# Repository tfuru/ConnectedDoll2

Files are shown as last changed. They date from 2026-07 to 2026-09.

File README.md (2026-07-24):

# オーディオストリーミングスタンド開発ボード ver.2
XIAO ESP32C3 に TFカード, RTC, オーディオアンプ  などを追加したオーディオストリーミングボード

## 参考ボード
[オーディオストリーミングスタンド開発ボード](https://github.com/bit-trade-one/ADE32CD-Connected-Doll) 

## 基板,外装
[board README.md](./board/circuit)

## ファームウェア
[firmware README.md](./board/firmware)

## サンプルアプリ
[app README.md](./app/)

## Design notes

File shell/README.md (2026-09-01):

# オーディオストリーミングスタンド開発ボード ver.2 ケース（外装）データ
XIAO ESP32C3 に TFカード, RTC, オーディオアンプなどを追加したオーディオストリーミングボード ケースのデータ

本ケースの3Dモデルデータは **OpenSCAD**（`.scad`）を用いてパラメータ設計・作成します。

## ケース イメージ図
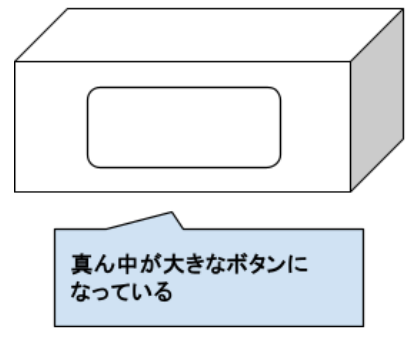
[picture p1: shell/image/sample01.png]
sample01
  
- 上下2分割（トップカバー / ボトムケース）構造の正方形ケース
- トップカバーの手前側面（フロント）に大型プッシュボタンを配置
- ボトムケース内部底面にスピーカー固定用ネジ穴を配置

## 主な部品

### 1. オーディオストリーミングスタンド開発ボード ver.2 基板
- **基板寸法**: 60mm × 60mm
- **角丸**: R = 2.0mm
- **取付穴**: 四隅 52mm × 52mm 位置に M2 ネジ穴
- **基板搭載部品**: XIAO ESP32C3, 横向きタクトスイッチ(EVQPUC02K), オンボードLED(WS2812B), 音量調整用アナログ可変抵抗, 各種コネクタ

### 2. スイッチ付き 単4電池×3本 電池ボックス
- **外形寸法**: 長さ 63.0mm × 幅 37.0mm × 高さ 17.0mm
- 電源スイッチ付き（スライドスイッチ）
- 配線取り出し口あり

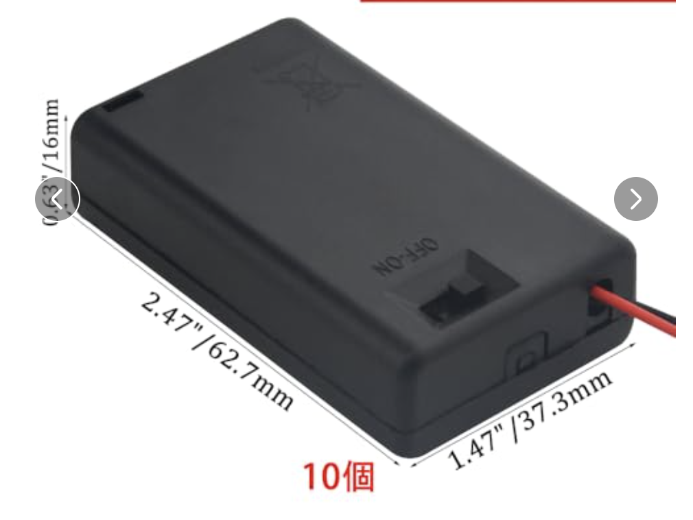
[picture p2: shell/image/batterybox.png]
batterybox


### 3. スピーカー TR-WS-2014B
- **本体外形寸法**: 20.0mm × 13.9mm × 厚み 4.5mm (取付フランジ含め 全幅 28.5mm)
- **取付穴ピッチ**: 24.7mm (M1.8ネジ対応)
- **出音口**: 取付耳側の長手側面スロットおよび前面開口（ケース前方 -Y 方向に向けて配置）
- **固定**: ボトムケース底面の M1.8 固定ボス（Y = -31.0mm / 前面方向へ2.5mm移動し電池ボックスとの間に1.75mmクリアランスを確保）にネジ止め

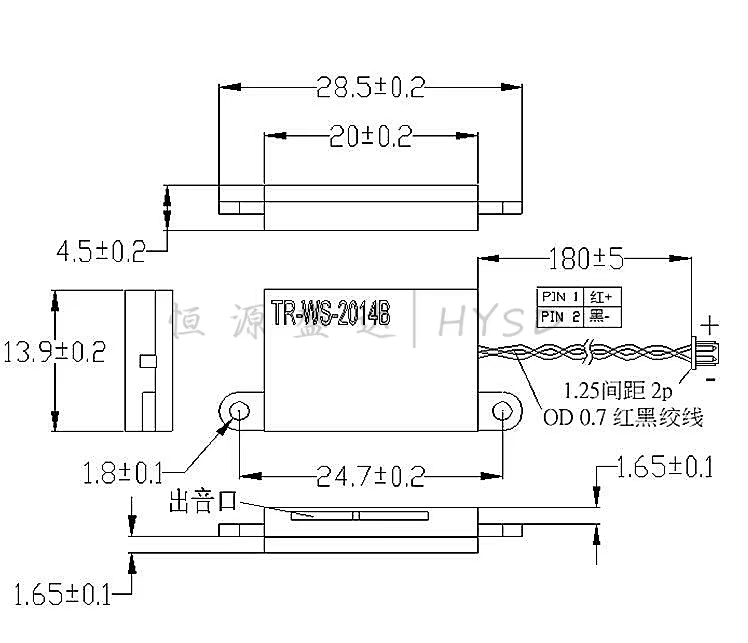
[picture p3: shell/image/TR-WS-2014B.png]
TR-WS-2014B


## ケース設計仕様

### 1. 構造 & レイアウト仕様
- **ケース形状**: 上下2分割ケース（外寸 約 68.8mm × 71.8mm、手前側壁を前方に +3.0mm 拡張して基板との間に 4.2mm の広大なクリアランスを確保）
- **トップカバー**:
  - 薄型リッド（天板カバー、高さ 8.0mm）
  - 上下締結ボス（M2 おねじ受けタッピングボス）
  - **右側面**: 音量調整用 スリット上部切り欠き＆指掛かりスカラップ＋**内側補強土手**（高さ3.0mm切り欠き、幅24.0mm×深さ1.4mmの45度テーパーすり鉢面取り。内壁側に厚み1.3mmの補強土手を盛り上げ、スカラップ切削後も純残存肉厚1.9mm〜2.0mmを完全担保）
- **ボトムケース**:
  - **フロント側面**: 大型プッシュボタン用 開口部（約 44mm × 18mm, R=3mm）
  - **右側面**: 音量調整用 スリット開口部＆指掛かりスカラップ＋**内側補強土手**（**20mmスペーサー対応 天端開放Uノッチ構造 & 45度すり鉢状スカラップ & 内側裏打ちフレーム**: 開口幅18.0mm × 高さ3.3mm, 開口範囲 Z = 24.7mm〜28.0mm, 外壁に幅24.0mm×深さ1.4mmのすり鉢状指逃げ凹みを形成。ケース内側に厚み1.3mmの補強土手を一体化して総肉厚3.3mmとすることで、スカラップ加工後の最薄部でも**純残存肉厚1.9mm〜2.0mm（基準1.5mm以上）**を確実に確保。合わせ面リム幅も2.0mm以上を維持し、基板端面（X=64.4mm）との間にも1.1mmの安全クリアランスを保持）
  - **内部底面**:
    - スピーカー（TR-WS-2014B）固定用ボス（M1.8, ピッチ24.7mm / 手前前面側）
    - **電池ボックス底面取り出し開口ベイ (64.0mm × 38.0mm)**: ケース分解不要で底面から電池ボックスを抜き差し可能
    - **高剛性 電池フタ受け座補強フレーム (上面 Z = 3.6mm, 実肉厚 2.0mm)**: リセス座面（幅1.5mm）をケース内側へ+1.6mm盛り上げ、従来の極薄0.4mmから2.0mm（5倍）へ大幅増強。手前ツメ受けスリット天井も含めて一体強化し、薄肉折損を完全根絶
    - **基板保護天井ストッパーリブ (Z = 19.2mm, 厚み2.2mm, 下面45度ブレース付き)**: 電池ボックスを底面から挿入した際に基板裏面（Z = 23.4mm）との間に安全空間（4.2mm）を保持。右側面ボリュームスリット開口部（Z=24.7mm〜28.0mm）より遥か下（Z≤21.4mm）に完全収容し、スリット開口・ダイヤル操作に一切干渉せず、下面45度テーパーブレースと垂直ガイド壁（幅20mm）の全面一体支持により折損を完全防止
    - **背面壁・底面一体型 垂直ガイドリブ (下面三角ブレース付き)**: 浮遊構造を完全排除し、背面内壁（Y=69.8mm）および健全な底面から前方開口端（Y=57.9mm）へ伸びる左右対称の垂直リブにより、電池ボックスの奥側ズレを適正クリアランス（0.5mm）で確実に拘束
    - **側壁垂直ガイドレール**: 電池ボックスの横揺れを抑え、スムーズな抜き差しを実現
    - **高剛性 M2六角スペーサー受け座パッド (52×52mmピッチ, パッド高2.4mm, 回り止め六角ポケット付, 締結座面肉厚 2.0mm)**: 底面ザグリ穴（深さ1.4mm）との間で実効肉厚 2.0mm（旧0.4mmの5倍）を確保し、ネジ締め付け時の割れ・突き抜けを完全防止
    - **回転ロックダイヤル受け座 & 補強台座ブロック**: 底面沈め込みポケット（深さ2.4mm）の真上を背面壁直結の頑丈な台座ブロック（厚み4.0mm）で完全被覆。内側からM2ネジ1本で保持され脱落しない高剛性キャプティブ構造
  - **底面外装 & 電池フタ**:
    - **高剛性アンダーカット潜り込み引っ掛け式 電池フタ (`battery_lid.scad`)**: 底面段差リセス（67.0×41.0mm）に対して全周 0.55mm の隙間（フタ外寸 65.9×39.9mm）を確保。フタ手前側のツメは底面外側表面に露出させず、裏面ステップ（Z=1.6mm〜2.7mm）から手前へ突出させてボトムケースのリセス座面裏側（厚み1.6mmの強固なフランジ）へ潜り込ませて係止。ボトム側スリット天井には高さ Z=4.8mm まで盛り上げた補強土手（純残存肉厚1.6mm確保）を設け、内部に電池ボックスを収容しても自重やスプリングの反力によるフタの浮き上がりを物理的に完全防止。外観は底面表面にツメ切り欠きのない美しいフラットデザイン
    - **スイッチアクセス開口窓 (幅23.0mm × 奥行き14.0mm, 角丸R2.5mm, 広大すり鉢状面取り1.8mm付き, 後方+5.0mmオフセット)**: 実機電池ボックスのスイッチ位置に合わせて後方へ+5.0mmシフト配置。スイッチの全可動範囲（ノブ右端・左端）を開口中央で完全にカバーし、成人の指の腹や爪先でフタを開けることなく軽快にON/OFF直接操作可能
    - **キャプティブ回転ロックダイヤル (`rotary_lock.scad`)**: 指先つまみリブ（コイン溝兼用）、Dカット施錠カム、90度回転リミッター内蔵
- **ポート・開口部の扱い**:
  - **Type-C ポート**: ケース開口なし（内部密閉）
  - **MicroSD スロット**: ケース開口なし（内部密閉）
  - **ボリューム**: 右側面スリットからダイヤル操作
  - **電源スイッチ**: ケース底面のスイッチアクセス開口窓から直接操作

### 2. 前面大型ボタン機構（側面配置・コイルスプリング＆インセット式M2アジャスタブル・プランジャー）
- ボトムケースの正面側壁に大型ボタンパーツを配置。
  - **基板接触回避・上方向+2.0mmシフト**: 20mm支柱スペーサー上の基板表面（Z=25.0mm）に対してネジ頭（φ3.5mm）が接触・干渉するのを完全に回避するため、プランジャーネジ位置を上方向へ +2.0mm オフセット（ボタン中心からのオフセット Y = +3.625mm, ネジ中心高さ Z=27.825mm）。ネジ頭下端（Z=26.075mm）と基板表面の間に 1.075mm の安全空間を確保しつつ、タクトスイッチ（EVQPUC02K）のアクチュエータを確実に押下。
  - **高肉厚・M2ネジ貫通防止構造**: ボタン全厚を **6.0mm**（ボタンキャップ厚み 4.2mm ＋ フランジ厚み 1.8mm）へ増厚。ケース外壁から 2.2mm 突出し、ストローク時も埋没せず快適な押し心地と高いガイド剛性を実現。
  - **インセット（埋め込み）ポケット ＆ 安全肉厚2.0mm確保**: ボタン裏面に深さ 1.5mm（φ5.0mm）のネジ頭収容ポケットおよび深さ 2.5mm のタッピング下穴を配置。全厚 6.0mm に対し穴底から表面まで **2.0mm** の安全肉厚を確保し、推奨 M2 なべ小ねじ（L=4mm）を奥まで締め切っても表面を一切貫通しない設計。
  - **基板との適正クリアランス（3.6mm）**: ボタンフランジ裏面から基板前端面まで **3.60mm**、タクトスイッチ接触面まで **3.80mm** の十分な可動・調整空間を確保。
  - **M2ネジによる無段階クリアランス調整**: M2 なべ小ねじ（L=4mm 推奨）をねじ込み、ドライバーでねじ込み深さを回すだけでスイッチ先端とのクリアランス（0.2mm〜0.5mm）および押し込み深さを自由に微調整可能。
- **市販マイクロコイルスプリング（押しバネ）復帰機構 & 高剛性・耐折損受け座ボス構造**:
  - ボタン裏面左右2箇所に φ3.4mm ポケットを設け、外径 φ3.0mm × 自由長 6〜8mm のマイクロコイルスプリングをボトムケース受け座ボスとの間に挟み込み、スムーズでガタつきのない極上の復帰フィーリングを実現。
  - **D型長円スパイン構造（曲げ剛性・断面係数3倍増）**: 直径 φ5.4mm の前方円筒の背後に φ6.2mm の後方スパイン円柱を一体化し、奥行きを 8.2mm に拡張。バネ穴裏面の肉厚を 2.9mm → 5.8mm（2倍）に倍増してノッチ破断を完全防止。
  - **前面壁直結サポートブロック（片持ち梁長さを半減）**: ボタンフランジ下端（Z=14.6mm）より下のデッドスペース（Z=0〜10.5mm）を全面活用し、ボス前面からケース前面内壁までを中実ブロックで直結一体化。実効的な片持ち長を 19.4mm → 9.5mm に半減し、曲げ応力を約 1/8 に低減。
  - **3方向三角ブレース ＆ 根元裾野テーパー**: ボタン押下・バネ圧縮荷重を受け止める後方 45° 三角ブレース（t=2.0mm）、横揺れや印刷時振動を抑える外側横ブレース（t=2.0mm）、底面裾野テーパーを配備。
  - **頂部肉厚の最適化**: ボス高さを Z=20.0mm に設定し、基板下面（Z=23.4mm）との 1.4mm クリアランスを保ちつつ、バネ穴上部の肉厚を 1.0mm → 1.6mm（+60%）に増厚。
- がたつき防止ガイドおよび適度な押下ストローク（約0.4〜1.0mm）を確保。

### 3. 締結・固定仕様 & 使用ネジ一覧
- **六角スペーサーによる基板独立固定 ＆ トップカバー直接締結構造**:
  - **下部 20mm スペーサー**: ボトム底面四隅（52mm × 52mm ピッチ）に **M2 六角両メススペーサー（20mm）** を配置し、底面ザグリ穴から **M2 × 5mm なべ小ねじ** で強固に締結。
  - **基板上 5mm スペーサー（基板独立固定）**: 基板表面の四隅に **M2 六角スペーサー（5mm: オスメスまたは両メス＋スタッド）** をねじ込み、基板を 20mm スペーサーとの間に単独で強固にクランプ固定。トップカバーを開閉しても基板が一切外れない抜群のメンテナンス性を実現。
  - **トップカバーからのダイレクト締結（ボス高 4.0mm ＆ M2 × 8mm ネジ）**:
    - 5mm スペーサー天面（Z = 30.0mm: ボトム天端 Z=28.0mm から 2.0mm 突出）を受け止めるため、トップカバー内側ボスの高さを **4.0mm** に設定。
    - トップカバー天面ザグリ穴（深さ1.4mm）から **M2 × 8mm なべ小ねじ** を挿入し、ボスを介して 5mm スペーサー上部めねじへ直接締結（樹脂肉厚 4.6mm ＋ スペーサーねじ込み深さ 3.4mm で強固に締結）。
- **回転ロックダイヤル固定**: 底面外側から **M2 × 5mm なべ小ねじ** をダイヤル中心穴へ貫通させ、ボトムケース側ソリッドボスのタッピング穴へ締結。ネジ頭はダイヤル表面ザグリ穴（深さ1.3mm）に完全沈み込み、外側からドライバー1本で着脱・回転トルク調整が容易なキャプティブ構造。
- **スピーカー**: ボトムケース底面の固定ボス（M1.8, 24.7mmピッチ）へネジ止め固定

#### 必要ネジ・金具規格および推奨長さ一覧

| 用途 / 締結箇所 | 規格 | 数量 | 推奨ネジ長さ (首下長) | 備考・締結内訳 |
| :--- | :--- | :---: | :--- | :--- |
| **メイン基板下部支柱** | **M2 六角両メススペーサー** | **4本** | **スペーサー長 20mm (二面幅4.0mm)** | ボトム底面と基板下面の間を支柱固定（下部めねじ締結） |
| **メイン基板固定スペーサー** | **M2 六角スペーサー** | **4本** | **スペーサー長 5mm (二面幅4.0mm)** | 基板表面四隅にねじ込み基板を独立固定、上端天面でトップカバーを着座受座 |
| **トップカバー締結** | **M2 なべ小ねじ** | **4本** | **L = 8 mm (6mm〜8mm)** | 天面ザグリから挿入しボス(4.0mm)を介して5mmスペーサー上部へ直接締結 |
| **ボトムケース・スペーサー締結** | **M2 なべ小ねじ** | **4本** | **L = 4 mm 〜 6 mm (推奨 5mm)** | ボトム底面ザグリ穴から挿入し20mmスペーサー下部めねじへ締結 |
| **回転ロックダイヤル支柱ピン** | **M2 なべ小ねじ** | **1本** | **L = 4 mm 〜 6 mm (推奨 5mm)** | 底面外側からダイヤル中央を貫通させボトム側ボスへ締結（外側から調整容易） |
| **前面ボタン調整プランジャー** | **M2 なべ小ねじ** | **1本** | **L = 4 mm 〜 6 mm (推奨 4mm)** | ボタン裏面ボスへねじ込み、タクトスイッチ押下量を無段階微調整 |
| **前面ボタン復帰押しバネ** | **マイクロコイルスプリング** | **2本** | **外径 φ3.0mm × 自由長 6〜8mm (線径0.3mm)** | ボタン裏面とボトムケース受け座の間に挟み込み、滑らかな復帰動作を実現 |
| **スピーカー固定** | **M1.8 タッピングねじ (または M1.7〜M2)** | **2本** | **L = 4 mm 〜 5 mm** | スピーカー耳フランジ(1.0mm) ＋ ボス有効深さ(3.5〜4.0mm) |
| **前面ボタン用吸着磁石** | **ネオジム磁石** | **2個** | **φ6.0mm × 厚み 3.0mm (または2.0〜3.0mm)** | ボタン表面左右の円筒ポケット（深さ3.0mm/径6.4mm, 導入テーパー付）に圧入・接着し、化粧パネル側M2ナットを吸着 |
| **化粧パネル用吸着ナット** | **M2 六角ナット (JIS規格/スチール製)** | **2個** | **厚み 1.6mm (二面幅 4.0mm)** | 化粧パネル左右の六角穴（二面幅4.4mm）に圧入・接着 |

### 4. 完全工具レス 電池交換手順
1. ケース底面の回転ロックダイヤルをつまみ、指先で90度回して「OPEN」位置（刻印マーク合わせ）にします。
2. 電池フタ奥側の指掛けネイルノッチに爪を掛け、フタを持ち上げて手前に引き抜きます。
3. 電池ボックスを底面開口から引き出し（リード線余裕長 50mm）、電池ボックスのフタをスライドさせて単4電池×3本を交換します。
4. 電池ボックスを内部へ戻し、電池フタを手前斜め約15°に傾けて手前の2箇所のツメをボトム内側のスリットへ潜り込ませ、パタンと倒してリセス座面へ収めます。
5. 回転ロックダイヤルを「LOCK」位置へ90度回して確実に施錠します。

## 構成パーツ一覧（OpenSCAD ファイル構成）
- **共通パラメータ**: `scad/params.scad`
1. **トップカバー**: `scad/top_cover.scad`
   - 手前側面エプロン壁、天面M2ネジ頭ザグリ穴（φ4.4mm × 1.8mm）、全通貫通穴（φ2.2mm）、基板押さえボス（高さ10.2mm）
2. **ボトムケース**: `scad/bottom_case.scad`
   - 前面大型ボタン開口部、右側面ボリュームスリット、スピーカー固定ボス（M1.8）、**底面電池取り出し開口ベイ（64×38mm）**、**回転ロック受け座ポケット＆90度リミッター溝**、**電池フタ受け座段差リセス**、**内側アンダーカットツメ受けスリット（Z=1.6〜3.2mm）＆スリット天井補強梁（Z=4.8mm）**、**内部基板保護天井ストッパー（Z=19.2mm）＆垂直ガイドレール**、前面スピーカー出音用スリット（7連バーチカルスリット）
3. **電池フタ（バッテリーリッド）**: `scad/battery_lid.scad`
   - 裏面手前側アンダーカット差し込み係止ツメ（左右2箇所, Z=1.6〜2.7mm）、**スイッチアクセス開口窓（23×14mm, テーパー面取り付き, 後方+5.0mmオフセット）**、奥側回転ロック受座円弧シェルフ（Dカット逃げ付き）、指掛けネイルノッチ
4. **回転ロックダイヤル**: `scad/rotary_lock.scad`
   - 指先つまみリブ（コイン溝兼用）、外周滑り止めセレーション、90度回転制動リミッターピン、Dカット施錠カム、**中心M2ネジ頭沈めザグリ穴＆貫通ピボット穴**
5. **前面ボタン（ボタンキャップ）**: `scad/front_button.scad`
   - 側面操作用大型ボタン、M2ネジ式アジャスタブル・プランジャーボス、裏面 左右2箇所 φ3.4mm コイルスプリングポケット、表面左右2箇所 φ6.4mm ネオジム磁石接着ポケット（導入テーパー付）
6. **3Dプリント一括出力用プレート**: `scad/print_plate.scad`
   - **超コンパクト垂直スタック一体型モデル**: ボトムケースの外寸（約 $69\text{mm} \times 72\text{mm}$）内に、電池フタおよび回転ロックダイヤルを中間層として完全内包スタック。部品間を離さずにベッド専有面積を最小化（約55%削減）し、全パーツ間に薄首サポートピラー（くびれ径 $\phi 1.3\text{mm}$）を配置。印刷後にニッパーでパチンと簡単に切り離せるランナーキット構造。（※前面ボタンは別色印刷対応のため単体 `front_button.stl` を推奨、`include_button=true` で追加可能）
7. **全体アセンブリ確認用**: `scad/main_assembly.scad`
   - 各パーツおよび基板・電池ボックス・スピーカー・締結ネジ・電池フタ・回転ロックの配置・干渉確認用（施錠/解錠および下方向分解シーケンス対応）

## STL 出力スクリプト
OpenSCAD CLI（コマンドライン）を利用して各 `.scad` ファイルから 3D プリント用 STL ファイルを一括・自動生成するビルドスクリプト（`export_stl.sh`）を作成・提供します。

- **出力予定 STL ファイル**:
  - `stl/print_plate_all.stl`（**★超コンパクト一括スタック印刷用**: ボトム＋フタ＋ロック＋トップを垂直スタック＆ニッパー切り離しサポート付きで 1 回でまとめてコンパクト印刷）
  - `stl/top_cover.stl`（トップカバー単体）
  - `stl/bottom_case.stl`（ボトムケース単体）
  - `stl/front_button.stl`（前面大型ボタン単体）
  - `stl/acrylic_panel.stl`（アクリル化粧パネル 3Dモデル）
- **アクリル加工用 2D ベクターファイル**:
  - `acrylic/acrylic_panel.dxf`（レーザーカット用 DXF）
  - `acrylic/acrylic_panel.svg`（レーザーカット / イラスト用 SVG）
- **プレビュー画像出力先**:
  - `image/dist/` 配下にレンダリングプレビュー画像（`print_plate_preview.png`, `top_cover_preview.png`, `bottom_case_preview.png`, `front_button_preview.png`, `acrylic_panel_preview.png`, `assembly_exploded.png`, `assembly_closed.png`）を自動生成

### コマンド例

#### スクリプトによる一括出力
```bash
# スクリプトに実行権限を付与して実行
chmod +x export_stl.sh
./export_stl.sh
```

#### 個別パーツのコマンドライン出力 (OpenSCAD CLI)
```bash
# 出力先ディレクトリの作成
mkdir -p stl image/dist

# 各パーツを STL としてレンダリング・出力
openscad -o stl/top_cover.stl scad/top_cover.scad
openscad -o stl/bottom_case.stl scad/bottom_case.scad
openscad -o stl/front_button.stl scad/front_button.scad
```

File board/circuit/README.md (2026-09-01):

# オーディオストリーミングスタンド開発ボード ver.2
XIAO ESP32C3 に TFカード, RTC, オーディオアンプ などを追加したボード

## 部品
JLCPCB にある部品を選定する 事とする   
https://jlcpcb.com/parts

| 回路種類 | 部品名 | 型番 | パッケージ |  JLCPCB Part | 備考 |
| ---- | --- | --- | ---- | ---- | --- |
| メインマイコン | マイコンボード | XIAO ESP32C3 | MODULE (17.8x21mm) | C19189385 | |
| オンボードLED | フルカラーLED  | WS2812B | SMD-5050 (5.0x5.0mm) | C4154882 | |
| 電源接続 | DCプラグコネクタ (外径5.5 mm、内径2.1 mm) | DC-005 2.0 | DIP | C16214 | Pin4: +5V, Pin2,3: GND |
| | 電源入力用コネクタ (PH) | B2B-PH-K-S(LF)(SN) | DIP | C131337 | 2pin PHコネクタ (オス, Pin1: +5V, Pin2: GND) |
| DCDC電源 | スイッチング電圧レギュレータ 3.3v | SY8089AAAC | SOT-23-5 | C78988 | |
||インダクタ 1.5μH / 6.3A | SMNR5040-1R5MT | SMD (5.0x5.0mm) | C467130 | 在庫あり代替品（シールド付） |
|| 積層セラミックコンデンサ 22μF / 16V | CL31A226KOCLNNC | SMD-1206 (3216) | C45783 | |
|| 精密チップ抵抗 45.3kΩ (±1%)| 0603WAF4532T5E | SMD-0603 (1608) | C23058 | |
|| 精密チップ抵抗 10kΩ (±1%) | RC0603FR-0710KL | SMD-0603 (1608) | C98220 | 在庫あり代替品 |
| 保護回路 | リセッタブルヒューズ | BSMD1206-110-16V | SMD-1206 (3216) | C2803346 | |
| 信号変換 | レベルシフタ | 74AHCT1G125GW | SOT-353 | C12495 | |
|| チップ抵抗 330Ω (±1%) | 0603WAF3300T5E | SMD-0603 (1608) | C23138 | |
| 逆流防止 | Pch MOSFET | AO3401A | SOT-23 | C15127 | |
|| ツェナーダイオード 5.1V | BZT52C5V1S | SOD-323 | C2118 | 在庫あり代替品 |
|| チップ抵抗 (±1%) 100kΩ | 0603WAF1003T5E | SMD-0603 (1608) | C25803 | |
| LED自動電源 | Pch MOSFET (ロードスイッチ) | AO3401A | SOT-23 | C15127 | 逆流防止用と共通 |
|| Nch MOSFET (ゲート駆動) | AO3400A | SOT-23 | C20917 | JLCPCB Basic Part |
|| 高速スイッチングダイオード | 1N4148WS | SOD-323 | C2128 | JLCPCB Basic Part (ピーク検波用) |
|| チップ抵抗 (±1%) 100kΩ | 0603WAF1003T5E | SMD-0603 (1608) | C25803 | プルアップ / プルダウン用 |
|| 積層セラミックコンデンサ 0.1μF | CL10B104KO8NNNC | SMD-0603 | C14663 | ピーク検波平滑用 |
| TFカード |  | DM3D-SF | SMD | C719027 | |
| RTC |  | DS3231MZ+TRL | SOIC-8 | C107410 | |
| オーディオ | オーディオアンプ | MAX98357AETE+T | TQFN-16-EP(3x3) | C910544 | |
| 操作UI | アナログ可変抵抗 10kΩ | RK10J11R0A0H | SMD | C470766 | 音量調整用 |
| | タクトスイッチ | EVQPUC02K | SMD (4.7x4.5mm) | C79174 | D0ピン(IO2)接続用 (横向きSMD) |
| 外部接続 | スピーカー接続用コネクタ (PH) | B2B-PH-K-S(LF)(SN) | DIP | C131337 | 2pin PHコネクタ (オス, 2.0mmピッチ) |
| | スピーカー接続用コネクタ (SH) | BM02B-SRSS-TB(LF)(SN) | SMD | C160388 | 2pin SHコネクタ (オス, 1.0mmピッチ, トップエントリー) |
| RTC電源 | CR1220用電池ホルダー | CR1220-2 | SMD | C70381 | 時刻バックアップ用保持器 |
| 電源/各IC | パスコン (積層セラ) 0.1μF | CL10B104KO8NNNC | SMD-0603 | C14663 | 各ICの電源用 (デカップリング) |
| | パスコン (積層セラ) 10μF | CL21A106KOFNNNE | SMD-0805 | C19702 | 電源平滑, アンプ電源補強, WS2812Bノイズ対策用 |
| | バルクコンデンサ (積層セラ) 47μF / 10V | CL31A476MPHNNNE | SMD-1206 (3216) | C96123 | 5V (V_BATT) 電源平滑・ESP32C3ノイズ対策用 |
| 通信ライン | プルアップ抵抗 1.5kΩ | 0603WAF1501T5E | SMD-0603 | C22843 | I2C(SDA/SCL)プルアップ用 |

## 回路参考

### 電源・保護回路 ブロック

Pch MOSFET (AO3401A) を用いた標準的な逆接続保護（ハイサイド）回路とする。

```
[DCジャック (DC1) Pin4 / PH端子 (CN3) Pin1 (+5V入力)] ──┬──> [AO3401A (C15127) の S(ソース)ピン]
                                                        │
                                                        └──> [ツェナーダイオード (C2118) の カソード(陰極)]

[AO3401A の G(ゲート)ピン] ──┬──> [ツェナーダイオード (C2118) の アノード(陽極)]
                             │
                             └──> [プルダウン抵抗 100kΩ (C25803)] ──> [GND]

[AO3401A の D(ドレイン)ピン] (正しく電源が入るとここから保護された電源が出力される)
    │
    └──> 🌟 ここが【リセッタブルヒューズ (C2803346)】の入力へ繋がります

※ 動作原理:
  - S(ソース) = +5V入力、D(ドレイン) = 保護後出力。
  - G(ゲート)は 100kΩ で GND へプルダウンされ、正常時 Vgs が負電圧となり MOSFET がON。
  - ツェナーダイオードは カソード=S(+5V側) / アノード=G(ゲート側) に接続し、
    Vgs を約5.1Vにクランプして MOSFET のゲート・ソース間を過電圧から保護する。
  - 逆接続時は Vgs が正となり MOSFET がOFFのまま導通しないため、後段を保護する。
```

```
[AO3401A の D(ドレイン)ピン] ──> [リセッタブルヒューズ (C2803346)] ──┬──> 🌟 各回路の【V_BATT】へ分配
                                                                      │
                                                                      └──> [バルクコンデンサ 47μF (C96123)] ──> [GND]

[電池のマイナス(−)] ───────────────────────────────> 🌍 すべての部品の【GND】へ接続
```

### 3.3V DCDCコンバータ回路 ブロック

```
                                 [インダクタ 1.5μH (C467130)]
                                     ┌─── LL ───┐
                                     │          │
[V_BATT] ──┬──> [IN (Pin4)] ─────── LX (Pin3)   ├──┬──> 🌟 各部品の【3.3V】電源へ
           │       │                            │  │
           │    [EN (Pin1)]                     │  └──> [コンデンサ 22μF (C45783)] ──> [GND]
           │                                    │
    [コンデンサ 10μF (C19702)]                  ├──> [分圧抵抗 45.3kΩ (C23058)]
           │                                    │         │
          [GND]                                 │      FB (Pin5)
                                                │         │
                                                │      [分圧抵抗 10kΩ (C25804)]
                                                │         │
                                                │        [GND]
                                                │
                                                └─────── [GND (Pin2)]

※ SY8089AAAC (C78988) は SOT-23-5 パッケージです。
```

### レベルシフタ ＆ LED回路 (自動電源遮断機能付き) ブロック

```
[XIAO D3 (GPIO5)] ──┬──> [74AHCT1G125GW (C12495) の A (Pin2)]
                    │
                    └──> [ダイオード 1N4148WS (C2128) の アノード]
                                │ (カソード)
                                ├──┬──> [Nch MOSFET AO3400A (C20917) の G(ゲート)]
                                │  │
                       [コンデンサ 0.1μF]  [プルダウン抵抗 100kΩ]
                                │  │
                               [GND]

[V_BATT] ──┬──> [Pch MOSFET AO3401A (C15127) の S(ソース)]
           │           │
     [プルアップ 100kΩ]  └── [D(ドレイン)] ──┬──> 🌟 各LED関連回路の【V_LED】電源へ
           │                               │
           ├───────────────────────────────┘
           │
  [AO3400A の D(ドレイン)]
  [AO3400A の S(ソース)] ──> [GND]

※ 動作原理:
  - D3ピンにデータパルス(800kHz)が出力されると、ダイオード経由で0.1μFコンデンサが急速充電され、AO3400A(N-MOS)がON。
  - AO3400Aが導通してAO3401A(P-MOS)のゲートをGNDへ引き下げ、P-MOSがONとなり V_LED が供給される。
  - D3がLOW(消灯・スリープ)になると、100kΩ抵抗で放電され約10msで自動的に V_LED が完全遮断される。

                    [74AHCT1G125GW (C12495)]
                          ┌───────┐
            [GND] ─── OE ─┤1  VCC ├─ V_LED ──┬──> [コンデンサ 0.1μF (C14663)] ──> [GND]
                          │       │
[XIAO D3 (GPIO5)] ──┬─ A ─┤2    Y ├─ [保護抵抗 330Ω (C23138)] ──> [WS2812B (C4154882) の DIN]
                    │     │       │
             [10kΩ] │     [GND] ──┤3      │
            (C25804)│             └───────┘
                    │
                  [GND] (※ ESP32C3起動時フロート防止プルダウン)

※ 74AHCT1G125GW は SOT-353 パッケージです。OEピンをGNDに落とすことで、バッファ出力を常に有効にします。
※ VCCを V_LED に接続することで、消灯スリープ時のDINへの寄生給電を防止します。

[WS2812B (C4154882) 単体の電源とパスコン]
  [VDD] ──> V_LED ──┬──> [コンデンサ 10μF (C19702)] ──> [GND] (※ ノイズ安定化用)
                    └──> [コンデンサ 0.1μF (C14663)] ──> [GND]
  [GND] ──> GND
  [DIN] ──> レベルシフタ出力 (330Ω経由)
  [DOUT] ──> (次のLEDを連結する場合は次のLEDのDINへ)
```

### オーディオ ブロック

```
                       [MAX98357AETE+T (C910544)]
                             ┌───────────┐
     [XIAO D6 (GPIO21)] ────┤ BCLK   VDD ├─ V_BATT (5V) ──┬──> [コンデンサ 10μF (C19702)] ──> [GND]
                             │           │                └──> [コンデンサ 0.1μF (C14663)] ──> [GND]
     [XIAO D7 (GPIO20)] ────┤ LRCLK  GND ├─ GND
                             │           │
     [XIAO D10 (GPIO10)] ───┤ DIN   GAIN ├─ GND (※ 9dBゲイン設定)
                             │           │
   V_BATT ── [10kΩ] ────────┤ SD_MODE   │
                             │      OUTP ├──┬─────────────> 🔊 [PH端子 CN1 (C131337) 1pin]
                             │           │  └─────────────> 🔊 [SH端子 CN2 (C160388) 1pin]
                             │           │
                             │      OUTN ├──┬─────────────> 🔊 [PH端子 CN1 (C131337) 2pin]
                             │           │  └─────────────> 🔊 [SH端子 CN2 (C160388) 2pin]
                             └───────────┘

※ MAX98357A は TQFN-16 パッケージです（上記は機能ピンを抜粋した接続図です）。
※ SD_MODE ピンを 10kΩ 以上の抵抗で VDD にプルアップすることで、L/Rの平均（モノラルミックス）を出力します。
※ スピーカー出力端子には、2.0mmピッチPH端子(CN1)および1.0mmピッチSH端子(CN2)を並列に配置し、外部スピーカーを接続可能とします。
```

### RTC ブロック

```
                       [DS3231MZ+TRL (C107410)]
                             ┌───────────┐
     [XIAO D4 (GPIO6)] ─────┤ SDA   VCC ├─ 3.3V ──┬──> [コンデンサ 0.1μF (C14663)] ──> [GND]
        │                    │           │
     [4.7kΩプルアップ]       │           │
        │                    │           │
      3.3V                   │           │
                             │           │
     [XIAO D5 (GPIO7)] ─────┤ SCL  VBAT ├─ [CR1220用電池ホルダー (C70381)] のプラス(+)極へ
        │                    │           │
     [4.7kΩプルアップ]       │      GND ├─ GND
        │                    └───────────┘
      3.3V

※ DS3231MZ は SOIC-8 パッケージです。
※ I2CのSDAおよびSCLラインは、3.3V電源へそれぞれ 4.7kΩ (C22843) のプルアップ抵抗を接続します。
※ 電池ホルダーのマイナス(-)極は GND に接続します。
```

### TFカード ブロック

```
                       [DM3D-SF (C719027)]
                             ┌───────────┐
     [XIAO D2 (GPIO4)] ─────┤ MOSI  VDD ├─ 3.3V ──┬──> [コンデンサ 0.1μF (C14663)] ──> [GND]
        │                    │           │
     [10kΩプルアップ]        │           │
        │                    │           │
      3.3V                   │           │
                             │           │
     [XIAO D9 (GPIO9)] ─────┤ MISO  GND ├─ GND
        │                    │           │
     [10kΩプルアップ]        │           │
        │                    │           │
      3.3V                   │           │
                             │           │
     [XIAO D8 (GPIO8)] ─────┤ SCK    CS ├─ GND (※ 常時有効設定)
        │                    └───────────┘
     [10kΩプルアップ]
        │
      3.3V

※ DM3D-SF は SMD タイプの MicroSD カードコネクタです（上記はSPI接続用の機能ピンの抜粋です）。
* 信号線（MOSI, MISO, SCK）は、SDカードの安定した初期化と動作のため、3.3V電源へそれぞれ 10kΩ (C25804) のプルアップ抵抗を接続します。
* CS（チップセレクト）ピンは、GPIOピン数を節約するため直接 GND に接続して常時アクティブ状態にします。
```

# EasyEDA Pro
回路作成ルール, 基板作成ルール は [AGENTS.md](/AGENTS.md) 記載のルールに従って設計データを作成する事

## 基板仕様 (PCB Specifications)

- **基板寸法**: 60mm × 60mm
- **角丸**: R=2.0mm
- **取付穴 (マウンティングホール)**: 四隅 52mm x 52mm 位置に M2 ネジ穴
- **GNDベタ (GND Copper Pour)**: 両面（Top/Bottom層）に配置（詳細な描画・孤立銅箔設定等は [AGENTS.md](/AGENTS.md) に従うこと）
- **基板外形とベタの座標位置**: 設定された基板寸法（60mm × 60mm）を基準として、原点 `(0, 0)` からの正の領域に完全に重ねて配置すること（詳細な座標設定のルールは [AGENTS.md](/AGENTS.md) に従うこと）
- **電源配線ルール (1A対応)**: 主要電源ライン（5V, VCC, V_BATT）のパターン幅は標準 `0.6 mm`（最小 `0.5 mm`）とする。その他の信号線は `0.2 mm` とする。

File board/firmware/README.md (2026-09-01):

# オーディオストリーミングスタンド開発ボード ver.2
XIAO ESP32C3 に TFカード, RTC, オーディオアンプ  などを追加したオーディオストリーミングボード

## 機能概要

本ファームウェアは、以下の周辺モジュールを統合制御し、BLEを介したファイルの送受信、定時スケジュール再生、スイッチによる割り込み音声トリガー、アナログ音量調節を提供します。

* **音声再生 (WAV/MP3 ハイブリッド対応)**
  * TF（MicroSD）カードに保存された音声ファイルをI2Sオーディオアンプ (MAX98357A) を経由してスピーカーから高品質再生します。
  * ファイルはデコード負荷の低い **WAV形式を優先的に再生** し、存在しない場合は **MP3形式** を探して再生します。
* **BLE通信 (時刻同期・ファイル転送)**
  * BLE経由でスマートフォン等の端末から音声ファイルを受信し、直接TFカードへ保存します（MTU最大517バイト対応）。
  * BLE経由で現在の正確な日時を取得し、RTC（リアルタイムクロック）へ反映します。
* **定時スケジュール再生 (RTC監視・自動タイマー復帰)**
  * 高精度RTC DS3231MZとESP32-C3の内部タイマーを連携し、設定されたスケジュール時刻になるとDeep Sleepから自動復帰して `/alarmX.wav` (無ければ `/alarmX.mp3`) を再生します。
* **物理UIコントロール & 省電力スリープ (Deep Sleep)**
  * **タクトスイッチ (GPIO復帰検知 / 再生・停止制御)**: Deep Sleep待機中であってもボタン押下により即座に復帰します（復帰時は音声は再生されず、起動後にボタンを押すことで `/trigger.wav` または `/trigger.mp3` を再生します）。また、音声再生中（トリガー再生またはアラーム再生）に押下した場合は再生を即座に停止（ストップ）します。
  * **アナログボリューム (可変抵抗)**: アナログ入力（ADC）により、オーディオアンプの出力音量をリアルタイム（0〜21段階）に調整します。
  * **自動Deep Sleep移行**: 音声再生中やBLE接続中以外の無操作アイドル状態が60秒間継続すると、LEDを完全消灯して自動的にDeep Sleep（超低消費電力待機）に移行します。次回アラーム時刻またはタクトスイッチ押下で瞬時に復帰します。

---

## 動作インジケータ (LED仕様)

オンボードのフルカラーLED (WS2812B) の点灯パターンによって、現在のシステムの動作状況を一目で確認できます。

| LEDの表示状態 | システム状況 |
|---|---|
| 🟢 **設定カラーでゆっくり明滅 (呼吸パルス)** | 待機状態 (アドバタイズ中 / 未接続) |
| 🔵 **青色で常時点灯** | BLE接続中 (待機) |
| 🔴 **赤色で高速点滅 (100ms周期)** | BLE経由のファイルデータ受信・転送中 |
| 🟣 **設定カラーで中速点滅 (250ms周期)** | スピーカーから音声 (WAV/MP3) 再生中 |

---

## BLE通信仕様 (通信プロトコル)

スマートフォンなどのセントラル（アプリ側）から以下のUUIDを使用して基板（`ConnectedDoll_Audio`）へアクセスします。

* **サービスUUID**: `4fafc201-1fb5-459e-8fcc-c5c9c331914b`

### キャラクタリスティック定義

#### 1. 時刻同期・取得用 (`beb5483e-36e1-4688-b7f5-ea07361b26a8` / Write & Read)
基板の時刻合わせ、および現在のデバイス時刻の取得を行います。
* **書き込み (Write)**: 以下のいずれかのフォーマットでデータを書き込んで時刻を同期します。
  * **バイナリ形式 (7バイト)**: `[YYYY_high, YYYY_low, MM, DD, HH, MM, SS]`
  * **文字列形式 (19バイト)**: `"YYYY-MM-DD HH:MM:SS"`
* **読み取り (Read)**:
  * 現在のデバイス時刻（RTCの現在時刻）を文字列形式で取得します。
  * 返り値: `"YYYY-MM-DD HH:MM:SS"` (19バイトの文字列)

#### 2. ファイル転送制御用 (`e32a4e2b-fbc6-4b95-a22a-28d88b409600` / Write)
ファイル受信の開始と終了を指示します。
* **開始コマンド**: `"START:[保存するファイル名]"` (例: `"START:trigger.wav"`)
  * このコマンドを受信すると、基板は該当名でTFカード上に新規ファイルを書き込みオープンします。
* **終了コマンド**: `"END"`
  * 受信を終了し、書き込み中だったファイルを正常にクローズしてSDカードに保存します。

#### 3. ファイルデータ受信用 (`7b01d784-fb3b-4ce1-897b-cfd1264c7847` / Write)
* ファイル転送中に、バイナリデータをシーケンシャル（順次）に書き込みます。
* 受信したデータは、現在オープンされているファイルに対して即座に追記（アペンド）されます。最大517バイトの拡張MTUに対応しています。

#### 4. アラームスケジュール設定用 (`e82d0001-fbc6-4b95-a22a-28d88b409600` / Write & Read)
最大5つのアラームスロット（Index 0〜4）の設定と削除を行います。
* **アラーム設定コマンド (Write)**: `"SET:[Index],[YYYY]-[MM]-[DD] [HH]:[MM]"`
  * 例: `"SET:1,2026-07-25 15:30"` (スロット1にアラームを登録。時間になると `/alarm1.wav` または `/alarm1.mp3` を再生)
* **アラーム削除コマンド (Write)**: `"DEL:[Index]"`
  * 例: `"DEL:1"` (スロット1のアラーム設定を削除し、無効化します)
* **設定の読み取り (Read)**: 
  * 現在の全スロットの設定情報をテキスト形式で取得します。
  * フォーマット: `[Index]:[Enabled],[Time];[Index]:...`
  * 返り値の例: `"0:1,2026-07-25 15:30;1:0;2:0;3:0;4:0"` (`0` は無効、`1` は有効を示す)

#### 5. LED明るさ設定用 (`e82d0002-fbc6-4b95-a22a-28d88b409600` / Write & Read)
デバイス上のフルカラーLED (WS2812B) の輝度（明るさ）を設定および取得します。
* **書き込み (Write)**: `0`〜`255` の範囲の輝度を文字列形式（例: `"128"`) または1バイトのバイナリ形式で書き込みます。
* **読み取り (Read)**: 現在設定されている輝度を文字列形式（例: `"128"`) で返します。設定値はフラッシュ（Preferences）に保存されます。

## GPIOなど

本基板で使用している XIAO ESP32C3 の GPIO 割り当ては以下の通りです。

| XIAOピン | ESP32-C3 GPIO | 接続先・機能 | 備考 |
|---|---|---|---|
| D0 | GPIO2 | タクトスイッチ | トリガー再生・停止用 (アクティブLOW) |
| D1 | GPIO3 | 可変抵抗 (10kΩ) | 音量調整用 (アナログ入力 / ADC) |
| D2 | GPIO4 | MicroSD MOSI | SPI通信用 (3.3Vへ10kΩプルアップ) |
| D3 | GPIO5 | フルカラーLED (WS2812B) | 5Vレベルシフタ経由でDINへ接続 |
| D4 | GPIO6 | RTC SDA | I2C通信用 (3.3Vへ1.5kΩプルアップ) |
| D5 | GPIO7 | RTC SCL | I2C通信用 (3.3Vへ1.5kΩプルアップ) |
| D6 | GPIO21 | I2S BCLK | オーディオアンプ (MAX98357A) 接続 |
| D7 | GPIO20 | I2S LRCLK | オーディオアンプ (MAX98357A) 接続 |
| D8 | GPIO8 | MicroSD SCK | SPI通信用 (3.3Vへ10kΩプルアップ) |
| D9 | GPIO9 | MicroSD MISO | SPI通信用 (3.3Vへ10kΩプルアップ) |
| D10 | GPIO10 | I2S DIN | オーディオアンプ (MAX98357A) 接続 |

* **MicroSD CS（チップセレクト）**: 基板上で直接 GND に接続されており、常時アクティブ（有効）に設定されているため GPIO ピンは消費しません。

## 開発環境
このプロジェクトは[PlatformIO](https://platformio.org/)を使用して開発されています。

- **Board:** `seeed_xiao_esp32c3`
- **Platform:** `espressif32`
- **Framework:** `arduino`

### ライブラリ
依存ライブラリは `platformio.ini` に記載されており、ビルド時に自動的にインストールされます。

### ファームウェアの書き込み
Makefileを使用してコマンドラインからビルドや書き込みを行うこともできます。
環境変数 `ENV` で対象ボードを指定できます（省略時は `platformio.ini` のデフォルトまたは全環境）。

```bash
# プロジェクトのビルド
make build

# ファームウェアの書き込み
make upload

# ファイルシステムの書き込み (dataフォルダ)
make uploadfs

# シリアルモニターの起動
make monitor

# ビルドアーティファクトの削除
make clean
```

## 推奨音声フォーマット

I2Sアンプによる音声再生時に「バチバチ」や「プツプツ」といったノイズ（または音の途切れ）が発生する場合、基板の配線抵抗やSDカードの応答遅延によるデータ破損・供給不足が起きている可能性が高いです。その場合は、以下の**軽量化フォーマット**に変換して再生をお試しください。

### 1. WAV 形式 (低CPU負荷・再生の安定性重視)
非圧縮のためCPU負荷がほぼゼロで、最も安定して動作します。立ち上がりが遅い回路（10kΩプルアップ等）では、サンプリングレートを下げてSDカードの読出頻度を抑えるのが最も効果的です。

- **推奨パラメータ**: **16 kHz / 16-bit / モノラル**
- **ffmpeg での変換コマンド例**:
  ```bash
  # 最も安定してノイズの出ない 16kHz モノラル WAV に変換する
  ffmpeg -i input.mp3 -acodec pcm_s16le -ac 1 -ar 16000 output.wav
  ```

### 2. MP3 形式 (ファイルサイズ極小・BLE転送速度重視)
WAVよりファイルサイズが小さいため、BLE転送時間が極めて短くなります。再生時のバチバチ音を防ぐため、ビットレートを下げて転送量とデコード計算の両方を最小化します。

- **推奨パラメータ**: **64 kbps (CBR固定) / 22.05 kHz / モノラル**
- **ffmpeg での変換コマンド例**:
  ```bash
  # 転送量と計算負荷を最小化する 64kbps固定 モノラル MP3 に変換する
  ffmpeg -i input.mp3 -codec:a libmp3lame -b:a 64k -ar 22050 -ac 1 output.mp3
  ```

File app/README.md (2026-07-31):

# ConnectedDoll2 BLE Controller App

BLE接続を通じて、「オーディオストリーミングスタンド開発ボード ver.2 (ConnectedDoll2)」への音声ファイル書き込み（転送）および日時アラーム設定を行うための Flutter モバイルアプリケーションです。

---

## 機能概要

1. **BLE デバイス検索 & 接続**
   - 近くにある `ConnectedDoll2` デバイスをスキャン・検出し、ワンタップで双方向BLE接続を確立します。
2. **推奨フォーマットへの音声自動変換 (トランスコード機能)**
   - ユーザーが選択した任意の音声ファイル（MP3など）を、ファームウェア側で最も安定してノイズなく再生できる推奨フォーマット（**16 kHz / 16-bit / モノラル WAV**）へアプリ内で自動変換します。
3. **WAVファイル書き込み (BLEファイル転送)**
   - 変換したWAVデータを、BLEのカスタムプロトコル（分割送信）を用いてデバイスのSDカードへ直接書き込みます。
   - `trigger.wav`（スイッチ再生用）および `alarm0.wav` 〜 `alarm4.wav`（アラーム用）の転送に対応。
4. **日時アラーム設定とファイル指定**
   - アラームスケジュール（最大5件、インデックス0〜4）の登録・削除・状態一覧表示。
   - アラームごとに異なる音源（`alarm0` 〜 `alarm4`）が自動で紐付けられます。

---

## 開発・ビルド環境

- **フレームワーク**: [Flutter](https://flutter.dev/) (3.x 系統推奨)
- **主要依存パッケージ**:
  - `universal_ble`: `^2.1.0` (クロスプラットフォーム対応のBLE通信ライブラリ)
  - `ffmpeg_kit_flutter_audio`: `^6.0.3` (音声ファイルの推奨フォーマット変換用)

---

## ビルド & 実行手順

### 1. 共通手順（依存関係の解決）
アプリディレクトリ内で以下のコマンドを実行し、パッケージをインストールします。
```bash
flutter pub get
```

### 2. Android での実行・ビルド

#### 実機 / エミュレータでの開発実行
Android端末をPCに接続（またはエミュレータを起動）し、以下のコマンドを実行します。
```bash
adb pair 192.168.10.110:35903

flutter run
```

#### リリース用 APK のビルド
```bash
flutter build apk --release
```
ビルド完了後、`build/app/outputs/flutter-apk/app-release.apk` にAPKファイルが生成されます。

#### 🛠 Android 開発時のトラブルシューティング
* **「ADB server didn't ACK」または adb の起動失敗エラーが出た場合**:
  ADBサーバー（Android Debug Bridge）が別のプロセスによってロックされている可能性があります。以下のコマンドでサーバーをリセットしてください。
  ```bash
  # ADBサーバーの強制終了と再起動
  adb kill-server
  adb start-server
  ```
  もし `adb` コマンド自体が見つからない場合は、パス（`/Users/t_furu/Library/Android/sdk/platform-tools` 等）を環境変数に追加するか、Android Studio からデバイス接続をリフレッシュしてください。

---

### 3. iOS での実行・ビルド

iOSアプリをビルド・実行するためには、Mac環境および以下のセットアップが必要です。

#### CocoaPods のインストール
iOSのネイティブプラグインを管理するため、CocoaPodsが必須です。
```bash
sudo gem install cocoapods
# または Homebrew を使用している場合:
brew install cocoapods
```

#### ポッドファイルのインストール
```bash
cd ios
pod install
cd ..
```

#### Xcode での署名（Signing）の設定
実機でBLE機能を使用するためには、Xcodeでのプロビジョニング署名が必要です。
1. Macで `ios/Runner.xcworkspace` を Xcode で開きます。
2. 左のプロジェクトツリーから最上部の `Runner` を選択します。
3. `Signing & Capabilities` タブを選択します。
4. `Team` でご自身のApple Developerアカウント（無料のPersonal Teamでも可）を選択し、`Bundle Identifier` を競合しないユニークなものに変更します。

#### iOS 実機での実行
```bash
flutter run
```

#### リリース用 IPA のビルド
```bash
flutter build ipa
```

---

### 4. CI/CD (GitHub Actions) での自動デバッグビルド

GitHub Actions を利用して、クラウド上で自動的に Android デバッグ APK をビルドして成果物を取得することができます。

#### 起動トリガー

1. **`debug-*` タグの Push**
   `debug-` から始まるタグを付与してリポジトリに push すると、自動的にデバッグビルドのワークフローが開始されます。
   ```bash
   git tag debug-v1.0.0
   git push origin debug-v1.0.0
   ```

2. **手動実行 (`workflow_dispatch`)**
   GitHub リポジトリの **Actions** タブ -> **Build App Debug** ワークフローを選択し、「Run workflow」ボタンから手動で起動することも可能です。

#### 成果物 (APK) の取得方法

1. **GitHub Releases ページから取得 (タグ Push 時)**
   `debug-*` タグを push して起動した場合、GitHub リポジトリの **Releases** ページに自動作成された Release（Pre-release）の **Assets** 一覧に `app-debug.apk` が直接添付されます。

2. **Actions タブの Artifacts から取得**
   GitHub の該当ワークフロー実行結果ページ下部にある **Artifacts** セクションから `app-debug-apk` (zip形式) をダウンロードして解凍することも可能です。

---

## BLE 通信仕様 (通信プロトコル)

アプリがデバイスと通信する際に使用する主要なUUIDおよびコマンド仕様です。

### 1. サービス & キャラクタリスティック UUID

| 項目 | UUID | プロパティ | 用途 |
| :--- | :--- | :---: | :--- |
| **Service (サービス)** | `e82d0000-fbc6-4b95-a22a-28d88b409600` | - | 本機専用BLEサービス |
| **Alarm Config (アラーム設定)** | `e82d0001-fbc6-4b95-a22a-28d88b409600` | Write / Read / Notify | アラーム日時の設定・削除・読出 |
| **File Transfer TX (データ送信)** | `e82d0002-fbc6-4b95-a22a-28d88b409600` | Write | 音声ファイルのバイナリ転送用 |
| **File Transfer RX (状態通知)** | `e82d0003-fbc6-4b95-a22a-28d88b409600` | Notify | 転送進捗・成否ステータスの受信用 |

### 2. アラーム設定プロトコル (`Alarm Config`)

このキャラクタリスティックを通じて、以下の文字列コマンドを送受信します。

* **アラーム設定 (Write)**: `SET:index,YYYY-MM-DD HH:MM` (例: `SET:0,2026-07-23 07:00`)
* **アラーム削除 (Write)**: `DEL:index` (例: `DEL:0`)
* **ステータス読出 (Read/Notify)**: デバイスから現在の全スロットの状態が返されます。
  * 返却形式: `index:0/1,YYYY-MM-DD HH:MM;...` (0=無効、1=有効)

### 3. ファイル転送プロトコル (`File Transfer`)

音声ファイルのバイナリデータを分割転送する際のヘッダープロトコルです。

* **ファイル転送開始ヘッダー (Write)**: `START:filename,filesize` (例: `START:trigger.wav,102400`)
* **データパケット (Write)**: ファイルの純粋なバイナリデータを一定サイズ（MTUサイズ以下）に分割して送信します。
* **終了ヘッダー (Write)**: `END` を送信して転送を完了します。

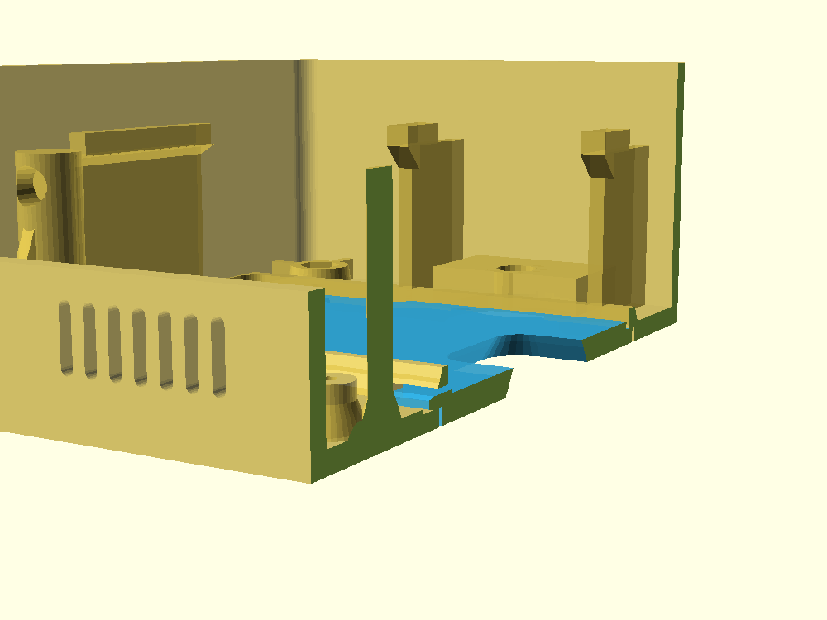
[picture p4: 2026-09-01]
shell/image/dist/battery_lid_tab_cutaway.png

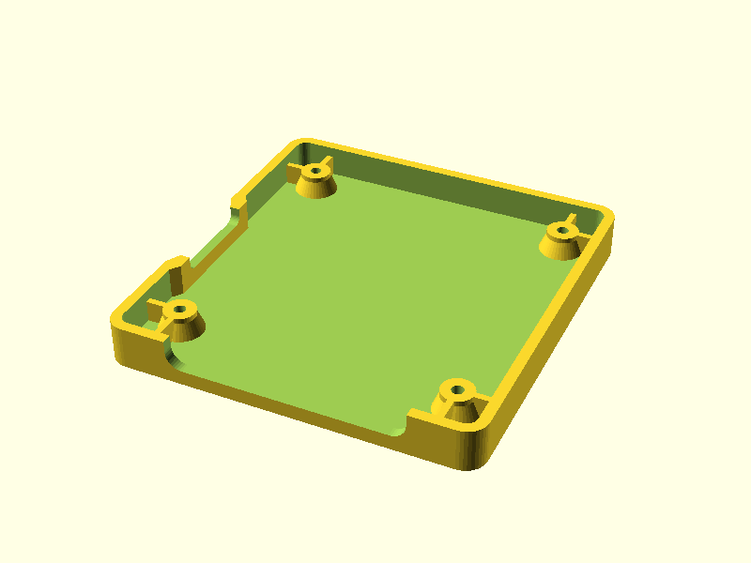
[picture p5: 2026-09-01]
shell/image/dist/top_cover_preview.png

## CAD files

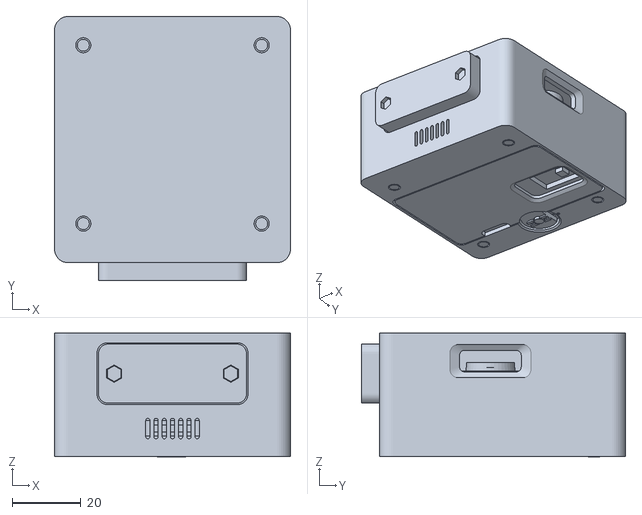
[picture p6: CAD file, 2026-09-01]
shell/stl/main_assembly_closed.stl
68.8 x 77.0 x 36.0

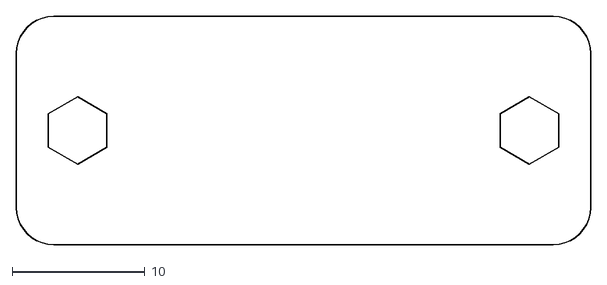
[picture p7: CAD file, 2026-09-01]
shell/acrylic/acrylic_panel.dxf
43.2 x 17.2

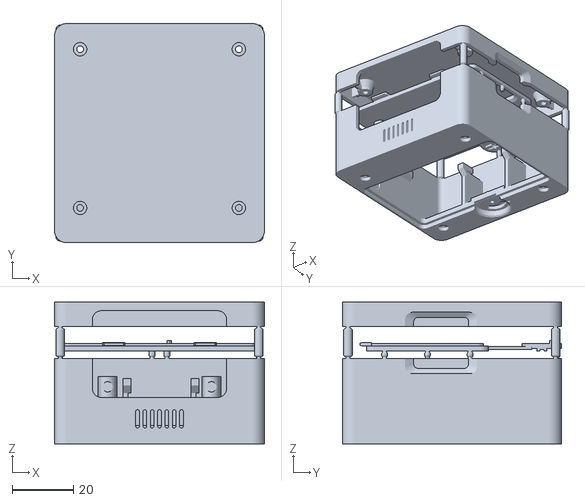
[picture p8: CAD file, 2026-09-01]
shell/stl/print_plate_all.stl
68.8 x 71.9 x 46.5

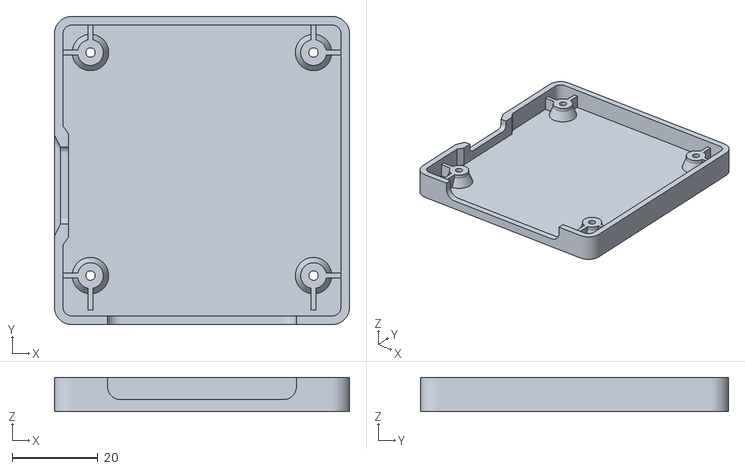
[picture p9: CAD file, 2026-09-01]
shell/stl/top_cover.stl
68.8 x 71.8 x 8.00

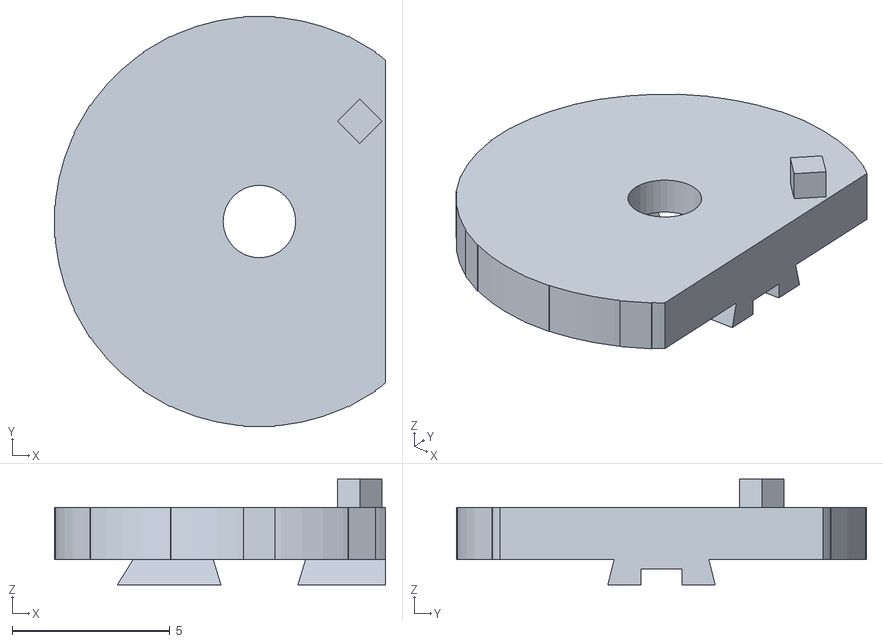
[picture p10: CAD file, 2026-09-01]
shell/stl/rotary_lock.stl
10.5 x 13.0 x 3.35

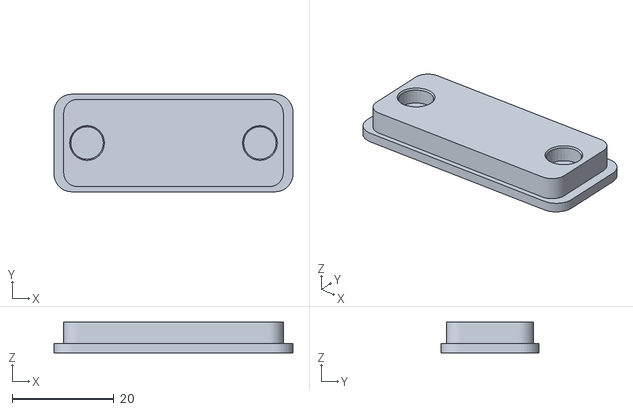
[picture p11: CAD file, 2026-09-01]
shell/stl/front_button.stl
47.0 x 19.2 x 6.00

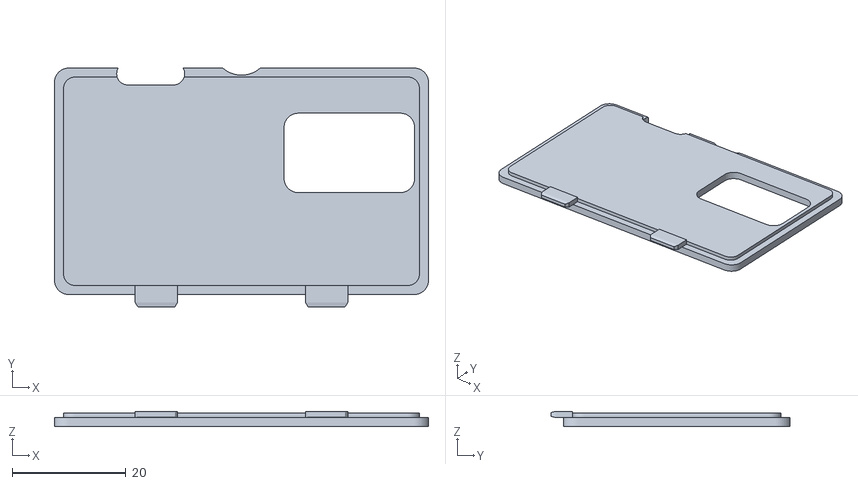
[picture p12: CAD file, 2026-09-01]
shell/stl/battery_lid.stl
65.9 x 42.1 x 2.70

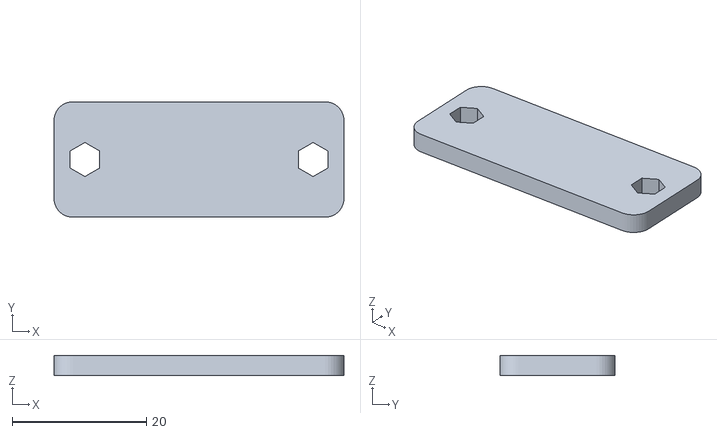
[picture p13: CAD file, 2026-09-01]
shell/stl/acrylic_panel.stl
43.2 x 17.2 x 3.00

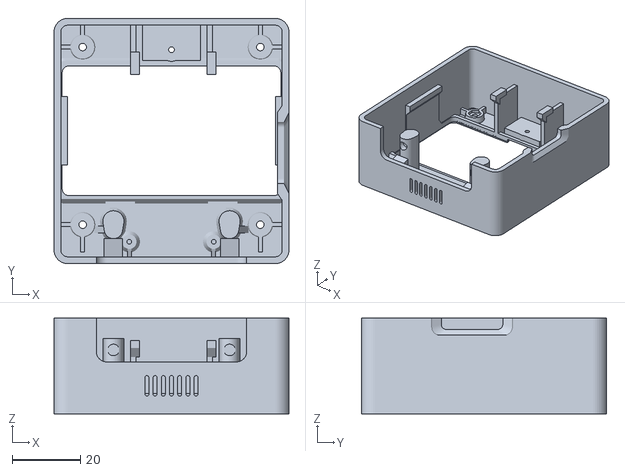
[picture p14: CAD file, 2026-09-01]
shell/stl/bottom_case.stl
68.8 x 71.8 x 28.0

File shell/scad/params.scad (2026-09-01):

// ==========================================
// ConnectedDoll2 Shell Parameters (params.scad)
// ==========================================

$fn = 40; // 円・フィレットの分割精度

// --- 基本ケース外形 ---
wall_thickness = 2.0;         // ケース肉厚
corner_radius  = 4.0;         // 外装の角丸半径
clearance      = 0.4;         // 嵌合・可動クリアランス

// --- メイン基板 (PCB) ---
pcb_width      = 60.0;
pcb_height     = 60.0;
pcb_thickness  = 1.6;
pcb_hole_pitch = 52.0;        // 取付穴ピッチ (四隅 52x52mm)
pcb_hole_dia   = 2.0;         // M2 穴

// --- スピーカー (TR-WS-2014B) ---
spk_body_w     = 20.0;        // 本体幅 (20.0mm)
spk_body_h     = 13.9;        // 本体奥行き (13.9mm)
spk_thickness  = 4.5;         // 本体厚み (4.5mm)
spk_ear_w      = 28.5;        // フランジ含む全幅 (28.5mm)
spk_ear_to_front = 1.65;      // 出音口端面から取付穴中心までの距離 (1.65mm)
spk_hole_pitch = 24.7;        // フランジ取付穴ピッチ (24.7mm)
spk_hole_dia   = 1.8;         // M1.8 穴
spk_boss_dia   = 4.2;
spk_boss_inner = 1.4;         // M1.8 タッピング穴径
spk_boss_h     = 4.0;

// --- スピーカー出音スリット（ボトムケース手前前面壁） ---
spk_slit_w        = 1.2;        // スリット幅 (1.2mm)
spk_slit_h        = 6.0;        // スリット高さ (6.0mm)
spk_slit_r        = 0.6;        // スリット上下端の角丸 (0.6mm: 3Dプリント時のブリッジ垂れ防止)
spk_slit_pitch    = 2.4;        // スリット間隔ピッチ (2.4mm: 肉厚1.2mmのリブ柱を形成)
spk_slit_count    = 7;          // スリット本数 (7本: 開口全幅 15.6mm)
spk_slit_center_z = 8.2;        // スリット中心高さ (Z=8.2mm: スピーカー出音口中心に完全一致)

// --- 前面ボタン（ボトムケース手前側面に配置） ---
btn_side_width        = 44.0;       // 側面ボタン開口幅
btn_side_height       = 18.0;       // 側面ボタン開口高さ (18.0mm: 天井内面Z=34mmに対し手前壁0.8mm、天面から2.8mm確保)
btn_side_radius       = 3.0;        // 側面ボタン角丸

btn_cap_depth         = 4.2;        // ボタンキャップ厚み（外壁から2.2mm突出、十分な押し心地とガイド長を確保）
btn_flange_t          = 1.8;        // 脱落防止フランジ厚み（剛性強化 1.8mm、全厚6.0mm）
btn_flange_w          = btn_side_width + 3.0;   // 47.0mm (左右抜け止めツバ幅: 片側+1.5mm)
btn_flange_h          = btn_side_height + 1.2;  // 19.2mm (上下抜け止めツバ高: 上下各0.6mm, 天板天井クリアランス+0.2mm)
btn_magnet_d          = 6.0;        // ネオジム磁石直径 (φ6.0mm)
btn_magnet_t          = 3.0;        // ネオジム磁石厚み (3.0mm)
btn_magnet_pitch_w    = 34.0;       // 左右磁石・ナット位置ピッチ (2個配置)
btn_magnet_pocket_d   = 6.4;        // ボタン側磁石埋め込みポケット径 (φ6.4mm: 3Dプリント収縮を吸収するクリアランス+0.4mm)
btn_magnet_pocket_chamfer = 0.3;    // ポケット開口部 導入テーパー面取り量 (引っかかり防止)
btn_magnet_pocket_depth = 3.0;      // ボタン側磁石埋め込みポケット深さ (3.0mm: 底面肉厚3.0mm確保)

// --- 前面化粧パネル（アクリル等）および M2 六角ナット仕様 ---
panel_nut_width       = 4.4;        // パネル側 M2 六角ナット二面幅 (対辺 4.0mm + 余裕0.4mm)
panel_nut_depth       = 1.6;        // パネル側 M2 六角ナット厚み / ポケット深さ (1.6mm)

// --- 前面ボタン 左右押しバネ（マイクロコイルスプリング）＆M2アジャスタブル・プランジャー ---
btn_spring_d            = 3.0;        // 押しバネ外径 (φ3.0mm)
btn_spring_pocket_d     = 3.4;        // バネ収容ポケット穴径 (φ3.4mm: 余裕+0.4mm)
btn_spring_pocket_depth = 2.0;        // ボタン側バネポケット深さ (2.0mm)
btn_spring_pitch_w      = 34.0;       // 左右押しバネ配置ピッチ (34.0mm: 左右均等対称)
btn_spring_offset_y     = -5.5;       // 押しバネYオフセット (磁石ポケットとの干渉回避: 下側 -5.5mm)
btn_spring_free_l       = 7.0;        // 押しバネ自由長目安 (6.0〜8.0mm)
btn_case_boss_pocket_d  = 2.5;        // ボトムケース側受けボス深さ (2.5mm)
btn_case_boss_outer_d   = 5.4;        // ボトムケース側受けボス前方外径 (φ5.4mm)
btn_case_boss_rear_d    = 6.2;        // ボトムケース側受けボス後方スパイン径 (φ6.2mm: D型長円化・断面係数3倍)
btn_case_boss_rear_offset = 2.4;      // 後方スパインYオフセット (2.4mm: 柱奥行き8.2mmへ大幅拡張)
btn_case_boss_front_h   = 10.5;       // 前面壁直結ベース高さ (Z=10.5mm: ボタンツバ下端14.6mmに対し4.1mmマージン)
btn_case_boss_top_h     = 20.0;       // ボス頂部高さ (Z=20.0mm: 基板下面Z=21.4mmに対し1.4mmマージン、穴上部肉厚1.6mm確保)
btn_case_boss_rear_brace_l = 4.0;     // 後方受圧三角ブレース長 (4.0mm: 電池フタツメ先端とクリアランス0.34mm確保し干渉ゼロ)
btn_case_boss_side_brace_l = 5.5;     // 外側横方向三角ブレース長 (5.5mm: X軸たわみ・印刷時振動を完全抑制)
btn_case_boss_y         = 9.5;        // ボトムケース側受けボス中心Y座標 (9.5mm)
btn_target_stroke       = 0.4;        // スイッチ作動ストローク目安 (約0.3〜0.5mm)
btn_m2_boss_outer_d     = 4.4;        // M2ネジ受けボス外径 (肉厚強化 φ4.4mm)
btn_m2_boss_inner_d     = 1.7;        // M2ネジ下穴径 (PLAタッピング用 φ1.7mm)
btn_m2_boss_h           = 0.0;        // インセット構造により裏面突出ボスは0mm (完全フラット)
btn_inset_pocket_d      = 5.0;        // M2ネジ頭インセット収容ポケット径 (φ5.0mm)
btn_inset_pocket_depth  = 1.5;        // M2ネジ頭インセット収容ポケット深さ (1.5mm)
btn_m2_tap_depth        = 2.5;        // ポケット底面からのタッピング下穴深さ (2.5mm: 全厚6.0mmに対し表面残存肉厚2.0mmを確保)
btn_plunger_screw_l     = 4.0;        // 推奨M2なべ小ねじ長さ (L=4〜6mm)

// --- ボリューム調整スリット（右側面に配置）および RK10J ダイヤル仕様 ---
vol_dial_d          = 14.0;       // ダイヤル外径 (φ14.0mm)
vol_dial_h          = 2.5;        // ダイヤル本体高さ (2.5mm)
vol_slit_width      = 18.0;       // ダイヤル操作スリット基本幅 (18.0mm: φ14mmに対し前後各2mmクリアランス)
vol_slit_radius     = 1.5;        // スリット隅角丸 (R=1.5mm)
vol_offset_y        = -5.0;       // Y軸方向オフセット（前方向へ5mm移動）
vol_slit_bottom_z   = 24.7;       // スリット下端高さ (基板表面25.0mmより0.3mm下: 内部露出を防ぎつつダイヤル全高を露出)
vol_slit_height     = 3.3;        // ボトム側スリット高さ (天面28.0mmまで開放するUノッチ形状: 28.0 - 24.7 = 3.3mm)
vol_slit_top_h      = 3.0;        // トップカバー側スリット切り欠き高さ (合わせ目Z=28.0mmから上方向へ3.0mm: 全高6.3mm開口)
vol_scallop_w       = 24.0;       // 指掛かりスカラップ（指逃げ凹み）幅 (24.0mm)
vol_scallop_r       = 2.5;        // スカラップ外周角丸 (R=2.5mm)
vol_scallop_chamfer = 1.4;        // スカラップすり鉢状面取り量 (45度テーパー: 深さ1.4mmザグリ)
vol_scallop_ext     = 1.8;        // スカラップ上下展開量 (スリット端から1.8mm上下へ滑らかにテーパー展開)
vol_dam_thick       = 1.3;        // スリット内側補強土手（裏打ちフレーム）盛り上げ肉厚 (1.3mm: 壁総肉厚3.3mm、純残存肉厚1.9〜2.0mm確保)
vol_dam_w           = vol_scallop_w + 3.0; // 補強土手全幅 (27.0mm: スカラップ全幅24mmを余裕で被覆)
vol_dam_taper_w     = 2.0;        // 補強土手両端の45度テーパー幅 (2.0mm: 応力集中防止・スムーズな導入)

// --- 電池ボックス (単4×3本 スイッチ付き) & 底面取り出しベイ ---
batt_length        = 63.0;        // 横幅
batt_width         = 37.0;        // 縦幅
batt_height        = 17.0;        // 厚み
batt_clearance     = 0.6;         // 電池ボックス収容クリアランス
batt_pos_y         = 1.5;         // 電池ボックス中心Yオフセット（手前スピーカーおよび奥側回転ロックとの最適バランス）
batt_stop_z        = wall_thickness + batt_height + 0.2; // 内部天井ストッパー高さ (Z = 19.2mm: 基板裏面22.2mmに対し3.0mmクリアランス)

// --- 底面開口ベイ (Battery Bay) ---
batt_bay_clearance = 0.5;         // 開口部クリアランス (全周0.5mm)
batt_bay_w         = batt_length + batt_bay_clearance * 2; // 64.0mm
batt_bay_d         = batt_width + batt_bay_clearance * 2;  // 38.0mm

// --- 電池フタ (Battery Lid) & 底面段差リセス座面 ---
batt_lid_t            = 1.6;         // フタ本体肉厚
batt_lid_flange       = 1.5;         // 段差受座幅 (1.5mm)
batt_lid_recess_w     = batt_bay_w + batt_lid_flange * 2; // ボトム側段差リセス外寸 幅 (67.0mm: 基準寸法固定)
batt_lid_recess_d     = batt_bay_d + batt_lid_flange * 2; // ボトム側段差リセス外寸 奥行き (41.0mm: 基準寸法固定)
batt_lid_recess_depth = batt_lid_t;  // 段差リセス深さ (1.6mm: ツライチ)
batt_lid_seat_z       = 3.6;         // 受け座補強フレーム上面高さ (底面Z=0基準: 3.6mm)
batt_lid_seat_t       = batt_lid_seat_z - batt_lid_recess_depth; // 受け座実肉厚 = 2.0mm (旧0.4mmの5倍、折損防止)

batt_lid_margin       = 0.55;        // フタ外周クリアランス (全周0.55mmの隙間を確保、3Dプリント干渉防止)
batt_lid_w            = batt_lid_recess_w - batt_lid_margin * 2; // 65.9mm (-0.5mm縮小)
batt_lid_d            = batt_lid_recess_d - batt_lid_margin * 2; // 39.9mm (-0.5mm縮小)
batt_lid_step_margin  = 0.65;        // 内側位置決めステップクリアランス (全周0.65mm隙間、開口部擦れ防止)

// --- 手前側差し込みツメ (Battery Lid Tabs) ＆ ボトム内側引っ掛けスリット ---
batt_tab_w            = 7.5;         // 手前側差し込みツメ幅 (7.5mm)
batt_tab_d            = 2.2;         // 差し込みツメ突出量 (フタベース端面から手前へ2.2mm突出)
batt_tab_t            = 1.1;         // 差し込みツメ厚み (スリット高さ1.6mmに対し上下余裕0.5mm確保)
batt_tab_z            = batt_lid_t;  // ツメ配置高さ (Z=1.6mm: フタ裏面ステップと面一から突出)
batt_tab_pitch        = 30.0;        // 左右2箇所ツメ配置ピッチ (30.0mm)

batt_slot_w           = 8.5;         // ボトム側ツメ受けスリット幅 (左右クリアランス各0.5mm確保)
batt_slot_d           = 2.6;         // ボトム側ツメ受けスリット深さ (突出量2.2mm+余裕0.4mm)
batt_slot_h           = 1.6;         // ボトム側ツメ受けスリット開口高さ (上下クリアランス0.5mm確保)
batt_slot_z           = batt_lid_recess_depth; // スリット底面高さ (Z=1.6mm: リセス座面裏側から開口)
batt_tab_roof_z       = 4.8;         // スリット天井補強フレーム高さ (スリット天井肉厚 4.8 - (1.6 + 1.6) = 1.6mm を確保)

// --- 電池ボックス スイッチアクセス開口窓 ---
batt_sw_w          = 23.0;        // スイッチ開口窓 幅 (X方向: +9.0mm拡大、右端+5.5mm/左端+3.5mm拡張)
batt_sw_d          = 14.0;        // スイッチ開口窓 奥行き (Y方向: +4.0mm拡大、指入れクリアランス確保)
batt_sw_r          = 2.5;         // スイッチ窓 角丸
batt_sw_offset_x   = 19.0;        // 電池ボックス中心からのXオフセット (スイッチ位置へ最適化)
batt_sw_offset_y   = 5.0;         // 電池ボックス中心からのYオフセット (後方へ+5.0mm移動、実機スイッチ位置に最適化)
batt_sw_chamfer    = 1.8;         // 底面外側 すり鉢状テーパー面取り量 (指先誘導・操作性向上)
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

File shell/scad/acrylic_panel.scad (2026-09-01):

// ==========================================
// ConnectedDoll2 Acrylic Panel (acrylic_panel.scad)
// ==========================================

include <params.scad>;

// 描画モード: "3d" または "2d" (DXF/SVG出力時はコマンドラインから -D mode=\"2d\" で指定)
mode = "3d";

// アクリルパネル寸法
panel_w      = btn_side_width - clearance * 2;   // 43.2mm
panel_h      = btn_side_height - clearance * 2;  // 17.2mm
panel_r      = btn_side_radius - clearance / 2;  // 角丸 R=2.8mm
panel_t      = btn_magnet_t;                     // 3.0mm (アクリル厚み)

nut_radius   = (panel_nut_width / 2) / cos(30);  // M2 六角ナット外接円半径 ($fn=6 で二面幅 4.4mm)

// 2D 外形プロファイル (DXF / SVG レーザー加工用)
module acrylic_panel_2d() {
    difference() {
        // 外形プレート (角丸長方形)
        hull() {
            translate([-panel_w/2 + panel_r, -panel_h/2 + panel_r]) circle(r=panel_r);
            translate([panel_w/2 - panel_r, -panel_h/2 + panel_r])  circle(r=panel_r);
            translate([panel_w/2 - panel_r, panel_h/2 - panel_r])   circle(r=panel_r);
            translate([-panel_w/2 + panel_r, panel_h/2 - panel_r])  circle(r=panel_r);
        }

        // 左右 2 箇所の M2 六角ナット埋め込み穴（高さ中央: 二面幅 4.4mm）
        for (dx = [-btn_magnet_pitch_w/2, btn_magnet_pitch_w/2]) {
            translate([dx, 0])
                rotate([0, 0, 30])
                    circle(r=nut_radius, $fn=6);
        }
    }
}

// 3D モデル (STL / プレビュー用)
module acrylic_panel_3d() {
    linear_extrude(height=panel_t)
        acrylic_panel_2d();
}

// モードに応じた描画
if (mode == "2d") {
    acrylic_panel_2d();
} else {
    acrylic_panel_3d();
}

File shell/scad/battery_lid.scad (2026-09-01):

// ==========================================
// ConnectedDoll2 Battery Lid (battery_lid.scad)
// 回転ロック式 底面電池フタ
// ==========================================

include <params.scad>;

module battery_switch_cutout() {
    // スイッチ操作開口窓 (深さ0.8mmまでの面取り + 垂直壁0.8mm以上を保持し薄刃化・ナイフエッジを完全防止)
    chamfer_depth = 0.8;
    // 1. 表面すり鉢状面取り部 (Z = -0.2 〜 chamfer_depth)
    hull() {
        for (dx = [-batt_sw_w/2 + batt_sw_r, batt_sw_w/2 - batt_sw_r]) {
            for (dy = [-batt_sw_d/2 + batt_sw_r, batt_sw_d/2 - batt_sw_r]) {
                translate([dx, dy, -0.2])
                    cylinder(h=0.01, r=batt_sw_r + batt_sw_chamfer, $fn=32);
                translate([dx, dy, chamfer_depth])
                    cylinder(h=0.01, r=batt_sw_r, $fn=32);
            }
        }
    }
    // 2. 内部ストレート貫通部 (Z = chamfer_depth 〜 全層貫通: 垂直壁厚み0.8mm以上を確保)
    hull() {
        for (dx = [-batt_sw_w/2 + batt_sw_r, batt_sw_w/2 - batt_sw_r]) {
            for (dy = [-batt_sw_d/2 + batt_sw_r, batt_sw_d/2 - batt_sw_r]) {
                translate([dx, dy, chamfer_depth - 0.01])
                    cylinder(h=batt_lid_t + 1.5, r=batt_sw_r, $fn=32);
            }
        }
    }
}

module battery_lid() {
    dial_rel_y = rotary_pos_y - batt_pos_y; // ダイヤル中心のフタ中心からの相対Y座標 (23.7mm)
    cam_shelf_r = rotary_dial_d / 2 - rotary_cam_overlap; // 4.7mm (Dカット逃げ半径)

    difference() {
        union() {
            // 1. フタ本体ベースプレート (厚み batt_lid_t = 1.6mm, 角丸 R=2.5mm)
            translate([-batt_lid_w/2, -batt_lid_d/2, 0])
                rounded_cube([batt_lid_w, batt_lid_d, batt_lid_t], 2.5);

            // 2. 内側位置決めステップ (深さ0.8mm: 開口部 64x38mm 内側に全周0.65mm隙間で嵌合、干渉防止)
            step_w = batt_bay_w - batt_lid_step_margin * 2;
            step_d = batt_bay_d - batt_lid_step_margin * 2;
            translate([-step_w/2, -step_d/2, batt_lid_t - 0.01])
                rounded_cube([step_w, step_d, 0.8], 2.0);

            // 3. 手前側 アンダーカット差し込み係止ツメ (左右2箇所: 裏面ステップ Z=1.6mm〜2.7mmから手前へ突出)
            step_front_y = -step_d / 2; // 内側ステップ手前端面 (-18.35mm)
            tab_tip_y = -batt_lid_d / 2 - batt_tab_d; // ツメ先端Y座標 (-22.15mm: ベース手前端より手前へ2.2mm突出)
            tab_total_d = step_front_y - tab_tip_y;   // ツメ総前後長 (約3.8mm: ステップと強固に一体化)

            for (dx = [-batt_tab_pitch / 2, batt_tab_pitch / 2]) {
                translate([dx - batt_tab_w / 2, tab_tip_y, batt_tab_z]) {
                    hull() {
                        // 根元側（ステップ手前壁と完全一体化）
                        translate([0, tab_total_d - 0.01, 0])
                            cube([batt_tab_w, 0.01, batt_tab_t]);
                        // 先端側（上下・左右に斜め差し込み用スムーズ導入テーパー付き）
                        translate([0.5, 0, 0.2])
                            cube([batt_tab_w - 1.0, 0.01, batt_tab_t - 0.4]);
                        // 中間部
                        translate([0, 0.8, 0])
                            cube([batt_tab_w, 0.01, batt_tab_t]);
                    }
                }
            }
        }

        // 4. スイッチ操作開口窓 (全層完全貫通)
        translate([batt_sw_offset_x, batt_sw_offset_y, 0])
            battery_switch_cutout();

        // 5. 奥側 回転ロック受け円弧ポケット & カム通過貫通穴
        translate([rotary_pos_x, dial_rel_y, 0]) {
            // (a) ダイヤルツバ受座シェルフ (深さ rotary_cam_shelf_z = 0.75mm: シェルフ残存肉厚 0.85mm を保持、外周クリアランス+0.6mmへ拡大)
            translate([0, 0, -0.2])
                cylinder(h=rotary_cam_shelf_z + 0.2, r=rotary_dial_d / 2 + 0.6, $fn=60);
            // (b) カム解錠時通過貫通穴 (半径 cam_shelf_r = 5.0mm: 全層貫通、通過クリアランス拡大)
            translate([0, 0, -0.2])
                cylinder(h=batt_lid_t + 2.0, r=cam_shelf_r + 0.3, $fn=60);
        }

        // 6. 指掛けネイルノッチ (奥側フタ端面: 爪でフタを持ち上げやすくする凹み)
        translate([-16.0, batt_lid_d/2 - 1.0, -0.1])
            hull() {
                translate([-4.0, 0, 0]) cylinder(h=batt_lid_t + 1.0, r=2.0, $fn=20);
                translate([4.0, 0, 0]) cylinder(h=batt_lid_t + 1.0, r=2.0, $fn=20);
            }
    }
}

// 単体プレビュー描画
battery_lid();

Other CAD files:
shell/scad/bottom_case.scad
shell/scad/cutaway_assembly.scad
shell/scad/front_button.scad
shell/scad/main_assembly.scad
shell/scad/print_plate.scad
shell/scad/rotary_lock.scad
shell/scad/top_cover.scad

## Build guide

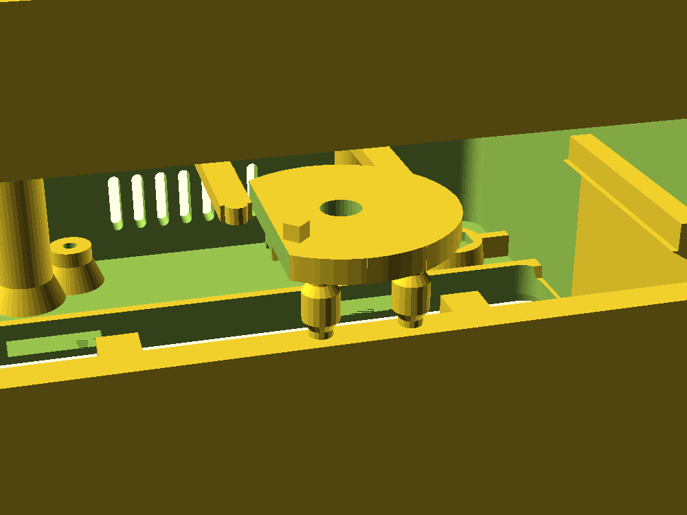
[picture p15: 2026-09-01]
shell/image/dist/print_plate_rear_zoom.png

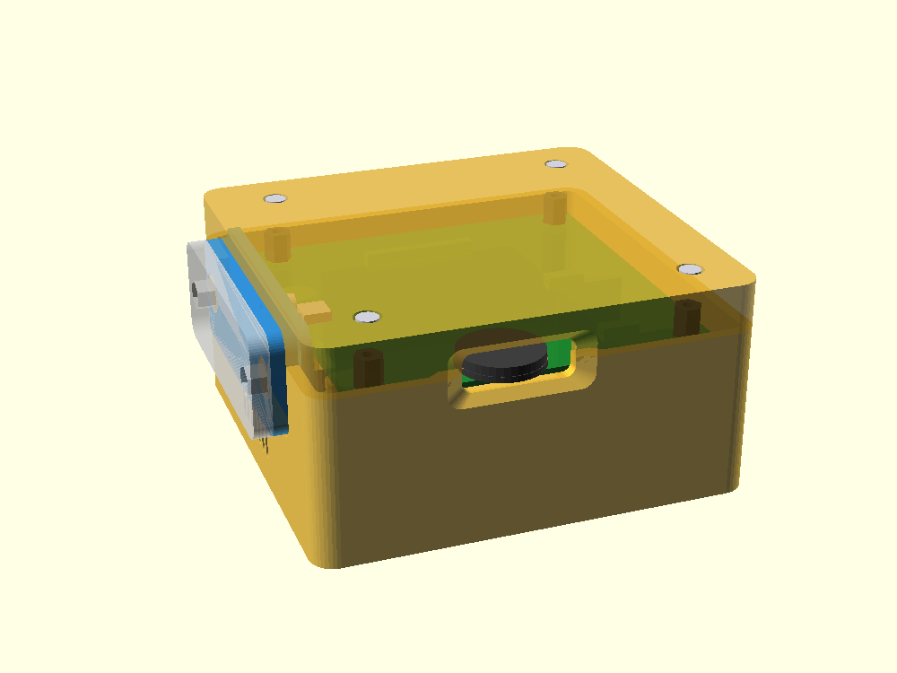
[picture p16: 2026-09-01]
shell/image/dist/assembly_closed.png

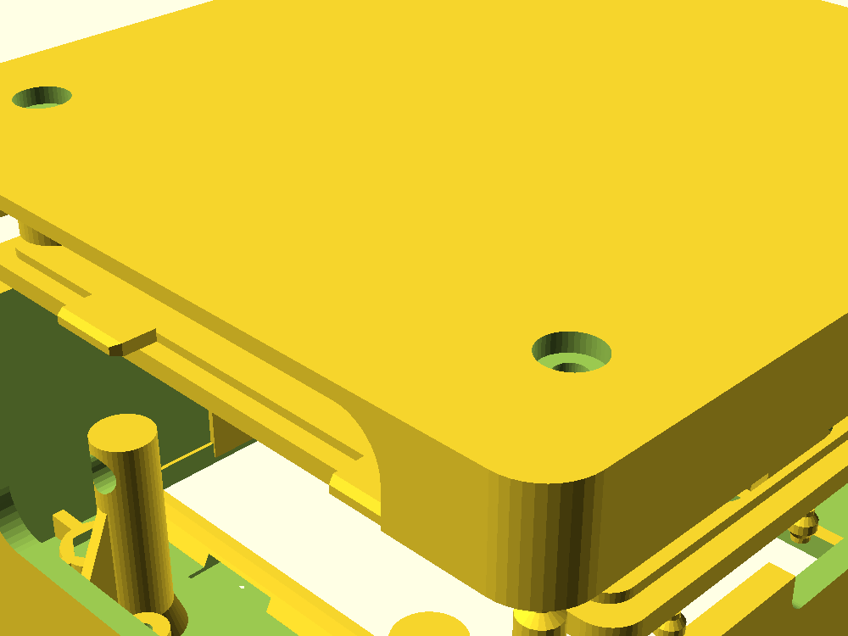
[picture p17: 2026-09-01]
shell/image/dist/print_plate_zoom.png

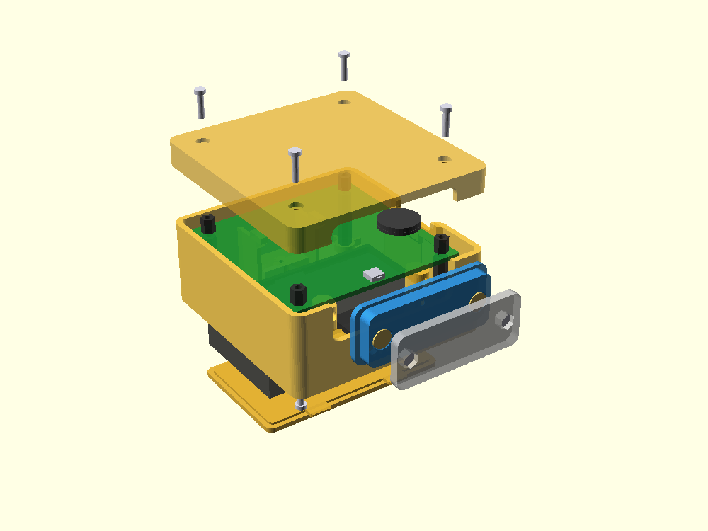
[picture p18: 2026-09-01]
shell/image/dist/assembly_exploded.png

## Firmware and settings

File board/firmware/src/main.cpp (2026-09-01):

#include "audio/alarm_manager.h"
#include "audio/audio_player.h"
#include "ble/ble_manager.h"
#include "hal/hal_io.h"
#include "hal/hal_power.h"
#include "hal/hal_rtc.h"
#include "hal/hal_sd.h"
#include "hal/hal_ota.h"
#include <Arduino.h>

// アイドルタイムアウト設定（無操作時にDeep Sleepへ移行するまでの時間: 60秒）
const unsigned long IDLE_SLEEP_TIMEOUT_MS = 60000;

// 音量の前回比率
float lastVolumeRatio = -1.0f;

void triggerButtonPlayback() {
  Serial.println("Triggering button playback (/trigger.wav or /trigger.mp3)...");
  if (HAL_SD::fileExists("/trigger.wav")) {
    AudioPlayer::playMP3("/trigger.wav");
  } else if (HAL_SD::fileExists("/trigger.mp3")) {
    AudioPlayer::playMP3("/trigger.mp3");
  } else {
    Serial.println("Error: trigger file (/trigger.wav or /trigger.mp3) not found on SD card.");
    // エラー表示としてLEDを一時的に赤く点灯
    HAL_IO::setLEDColor(100, 0, 0);
    delay(300);
  }
}

void setup() {
  Serial.begin(115200);
  delay(500);
  Serial.println("=========================================");
  Serial.println("Starting ConnectedDoll2 Audio Stand Board");
  Serial.println("=========================================");

  // 各ハードウェアモジュールの初期化
  HAL_Power::init();
  HAL_IO::init();
  HAL_SD::init();

  // 起動時の保留中ファームウェア更新チェック
  if (HAL_OTA::hasPendingUpdate("/update.bin")) {
    Serial.println("[Boot] Detected /update.bin on SD card. Processing OTA update...");
    HAL_OTA::performUpdateFromSD("/update.bin");
  } else if (HAL_OTA::hasPendingUpdate("/firmware.bin")) {
    Serial.println("[Boot] Detected /firmware.bin on SD card. Processing OTA update...");
    HAL_OTA::performUpdateFromSD("/firmware.bin");
  }

  HAL_RTC::init();
  AudioPlayer::init();
  AlarmManager::init();

  // スリープ復帰理由の確認
  esp_sleep_wakeup_cause_t wakeup_reason = HAL_Power::getWakeupCause();
  Serial.printf("[Power] Wakeup reason: %d\n", wakeup_reason);

  if (wakeup_reason == ESP_SLEEP_WAKEUP_GPIO) {
    Serial.println("[Power] Woken up by Tact Switch (GPIO2) - Audio playback skipped on wakeup.");
  } else if (wakeup_reason == ESP_SLEEP_WAKEUP_TIMER) {
    Serial.println("[Power] Woken up by RTC Timer Alarm!");
    DateTime now = HAL_RTC::getCurrentTime();
    AlarmManager::update(now);
  } else {
    Serial.println("[Power] Normal boot / Power-on reset.");
  }

  // BLEサーバー起動
  BLEManager::init("ConnectedDoll2");
  BLEManager::startAdvertising();

  uint8_t tr, tg, tb;
  HAL_IO::getThemeColor(tr, tg, tb);
  HAL_IO::setLEDColor(tr, tg, tb); // 起動完了: 推しカラー点灯
  HAL_Power::resetIdleTimer();
  Serial.println("System Initialization Complete.");
}

void loop() {
  // 状態更新ポーリング
  HAL_IO::update();
  AudioPlayer::update();
  BLEManager::processTransferBuffer();

  // 音声再生中・BLE接続中・ファイル転送中はアイドルタイマーを常時リセット（スリープ抑止）
  if (AudioPlayer::isPlaying() || BLEManager::isConnected() || BLEManager::isTransferringFile()) {
    HAL_Power::resetIdleTimer();
  }

  // --- 状態に合わせたLEDイルミネーション制御 ---
  static bool wasAudioPlaying = false;
  static unsigned long lastPlayFlash = 0;
  static bool playLedState = true;

  if (BLEManager::isTransferringFile()) {
    wasAudioPlaying = false;
    // BLEファイル転送中: 赤の高速点滅 (100ms)
    static unsigned long lastLedFlash = 0;
    static bool ledState = false;
    if (millis() - lastLedFlash > 100) {
      ledState = !ledState;
      if (ledState)
        HAL_IO::setLEDColor(50, 0, 0);
      else
        HAL_IO::setLEDColor(0, 0, 0);
      lastLedFlash = millis();
    }
  } else if (AudioPlayer::isPlaying()) {
    // 音声再生中: 設定カラー基準で中速点滅 (250ms点灯 / 250ms消灯)
    if (!wasAudioPlaying) {
      wasAudioPlaying = true;
      playLedState = true;
      lastPlayFlash = millis();
    }
    if (millis() - lastPlayFlash > 250) {
      playLedState = !playLedState;
      lastPlayFlash = millis();
    }
    if (playLedState) {
      uint8_t tr, tg, tb;
      HAL_IO::getThemeColor(tr, tg, tb);
      HAL_IO::setLEDColor(tr, tg, tb);
    } else {
      HAL_IO::setLEDColor(0, 0, 0);
    }
  } else if (BLEManager::isConnected()) {
    wasAudioPlaying = false;
    // BLE接続中: 青色点灯
    HAL_IO::setLEDColor(0, 0, 50);
  } else {
    wasAudioPlaying = false;
    // 待機状態: 推しカラーでゆっくりブレス明滅
    static unsigned long lastLedBreath = 0;
    static int breathVal = 5;
    static int breathDir = 1;
    if (millis() - lastLedBreath > 20) {
      breathVal += breathDir;
      if (breathVal >= 50 || breathVal <= 5) {
        breathDir = -breathDir;
      }
      uint8_t tr, tg, tb;
      HAL_IO::getThemeColor(tr, tg, tb);
      uint8_t r = (uint16_t)tr * breathVal / 50;
      uint8_t g = (uint16_t)tg * breathVal / 50;
      uint8_t b = (uint16_t)tb * breathVal / 50;
      HAL_IO::setLEDColor(r, g, b);
      lastLedBreath = millis();
    }
  }

  // --- ボリュームダイヤル (アナログ可変抵抗) の処理 ---
  static unsigned long lastVolCheck = 0;
  if (millis() - lastVolCheck > 100) { // 100msごとに間引いてCPUブロックを防止
    lastVolCheck = millis();
    float volRatio = HAL_IO::readVolume();
    // 誤検出を防ぐため 5% 以上の変化があった場合のみ更新
    if (abs(volRatio - lastVolumeRatio) > 0.05f) {
      lastVolumeRatio = volRatio;
      HAL_Power::resetIdleTimer();
      // ESP32-audioI2S の音量範囲は 0 ~ 21
      uint8_t targetVol = (uint8_t)(volRatio * 21.0f);
      AudioPlayer::setVolume(targetVol);
      Serial.printf("Volume updated: %d / 21 (ratio: %.2f)\n", targetVol,
                    volRatio);
    }
  }

  // --- タクトスイッチによる特定ファイル再生 (WAV優先、次点でMP3) / 再生中停止 ---
  if (HAL_IO::isKeyPressed()) {
    HAL_Power::resetIdleTimer();
    if (AudioPlayer::isPlaying()) {
      Serial.println("Button Pressed while playing! Stopping playback...");
      AudioPlayer::stop();
    } else {
      Serial.println("Button Pressed! Triggering playback...");
      triggerButtonPlayback();
    }
  }

  // --- RTCによる複数日時スケジュール再生 (WAV優先、次点でMP3) ---
  static unsigned long lastTimeCheck = 0;
  if (millis() - lastTimeCheck > 1000) { // 1秒間隔で時刻監視
    lastTimeCheck = millis();
    DateTime now = HAL_RTC::getCurrentTime();

    // 複数スロットアラームの監視とトリガー
    AlarmManager::update(now);

    // 10秒ごとにシリアルへ時刻と現在のアラーム設定を表示するデバッグログ
    static int debugTick = 0;
    if (++debugTick >= 10) {
      debugTick = 0;
      Serial.printf("[RTC Log] Current Time: %s | Alarms: %s\n",
                    HAL_RTC::getCurrentTimeStr().c_str(),
                    AlarmManager::getSchedulesStr().c_str());
    }
  }

  // --- アイドル状態監視とDeep Sleep移行判定 ---
  // BLE接続中・ファイル転送中・音声再生中は絶対にスリープに入らない
  if (!BLEManager::isConnected() && !BLEManager::isTransferringFile() && !AudioPlayer::isPlaying()) {
    if (HAL_Power::isIdleTimeout(IDLE_SLEEP_TIMEOUT_MS)) {
      Serial.println("[Power] Idle timeout reached without active connection or playback.");
      DateTime now = HAL_RTC::getCurrentTime();
      int64_t secondsToNext = AlarmManager::getSecondsToNextAlarm(now);
      
      uint64_t sleepDurationUs = 0;
      if (secondsToNext > 0) {
        Serial.printf("[Power] Next alarm in %lld seconds (%s)\n",
                      secondsToNext, HAL_RTC::getCurrentTimeStr().c_str());
        sleepDurationUs = (uint64_t)secondsToNext * 1000000ULL;
      } else {
        Serial.println("[Power] No active alarms scheduled.");
      }
      
      HAL_Power::enterDeepSleep(sleepDurationUs);
    }
  } else {
    // 接続・アクティビティ中は常にアイドルタイマーを最新化
    HAL_Power::resetIdleTimer();
  }
}

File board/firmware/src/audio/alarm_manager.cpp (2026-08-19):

#include "alarm_manager.h"
#include "audio_player.h"
#include "../hal/hal_sd.h"

AlarmSchedule AlarmManager::schedules[MAX_ALARMS];
int AlarmManager::lastTriggeredDay[MAX_ALARMS];
Preferences AlarmManager::preferences;

void AlarmManager::init() {
    for (int i = 0; i < MAX_ALARMS; i++) {
        lastTriggeredDay[i] = -1;
    }
    loadSettings();
}

void AlarmManager::loadSettings() {
    preferences.begin("alarm_conf", false);
    
    for (uint8_t i = 0; i < MAX_ALARMS; i++) {
        char key_en[8], key_da[8], key_yr[8], key_mo[8], key_dy[8], key_hr[8], key_mn[8];
        snprintf(key_en, sizeof(key_en), "en_%d", i);
        snprintf(key_da, sizeof(key_da), "da_%d", i);
        snprintf(key_yr, sizeof(key_yr), "yr_%d", i);
        snprintf(key_mo, sizeof(key_mo), "mo_%d", i);
        snprintf(key_dy, sizeof(key_dy), "dy_%d", i);
        snprintf(key_hr, sizeof(key_hr), "hr_%d", i);
        snprintf(key_mn, sizeof(key_mn), "mn_%d", i);

        schedules[i].enabled = preferences.getBool(key_en, false);
        schedules[i].isDaily = preferences.getBool(key_da, false);
        schedules[i].year = preferences.getUShort(key_yr, 0);
        schedules[i].month = preferences.getUChar(key_mo, 0);
        schedules[i].day = preferences.getUChar(key_dy, 0);
        schedules[i].hour = preferences.getUChar(key_hr, 0);
        schedules[i].minute = preferences.getUChar(key_mn, 0);
    }
    preferences.end();
    Serial.println("Alarm settings loaded from Preferences.");
}

void AlarmManager::saveSettings(uint8_t index) {
    if (index >= MAX_ALARMS) return;
    
    preferences.begin("alarm_conf", false);
    
    char key_en[8], key_da[8], key_yr[8], key_mo[8], key_dy[8], key_hr[8], key_mn[8];
    snprintf(key_en, sizeof(key_en), "en_%d", index);
    snprintf(key_da, sizeof(key_da), "da_%d", index);
    snprintf(key_yr, sizeof(key_yr), "yr_%d", index);
    snprintf(key_mo, sizeof(key_mo), "mo_%d", index);
    snprintf(key_dy, sizeof(key_dy), "dy_%d", index);
    snprintf(key_hr, sizeof(key_hr), "hr_%d", index);
    snprintf(key_mn, sizeof(key_mn), "mn_%d", index);

    preferences.putBool(key_en, schedules[index].enabled);
    preferences.putBool(key_da, schedules[index].isDaily);
    preferences.putUShort(key_yr, schedules[index].year);
    preferences.putUChar(key_mo, schedules[index].month);
    preferences.putUChar(key_dy, schedules[index].day);
    preferences.putUChar(key_hr, schedules[index].hour);
    preferences.putUChar(key_mn, schedules[index].minute);
    
    preferences.end();
    Serial.printf("Alarm slot %d configuration updated in NVS.\n", index);
}

bool AlarmManager::setAlarm(uint8_t index, uint16_t year, uint8_t month, uint8_t day, uint8_t hour, uint8_t minute, bool isDaily) {
    if (index >= MAX_ALARMS) return false;
    
    schedules[index].enabled = true;
    schedules[index].isDaily = isDaily;
    schedules[index].year = year;
    schedules[index].month = month;
    schedules[index].day = day;
    schedules[index].hour = hour;
    schedules[index].minute = minute;
    
    lastTriggeredDay[index] = -1; // ロックを解除して即時反応可能にする
    
    saveSettings(index);
    return true;
}

bool AlarmManager::deleteAlarm(uint8_t index) {
    if (index >= MAX_ALARMS) return false;
    
    schedules[index].enabled = false;
    saveSettings(index);
    return true;
}

String AlarmManager::getSchedulesStr() {
    // フォーマット: "0:1,2026-07-25 15:30;1:1,DAILY 18:00;..."
    String res = "";
    for (uint8_t i = 0; i < MAX_ALARMS; i++) {
        res += String(i) + ":";
        if (schedules[i].enabled) {
            char buf[48];
            if (schedules[i].isDaily) {
                snprintf(buf, sizeof(buf), "1,DAILY %02d:%02d",
                         schedules[i].hour, schedules[i].minute);
            } else {
                snprintf(buf, sizeof(buf), "1,%04d-%02d-%02d %02d:%02d",
                         schedules[i].year, schedules[i].month, schedules[i].day,
                         schedules[i].hour, schedules[i].minute);
            }
            res += String(buf);
        } else {
            res += "0";
        }
        if (i < MAX_ALARMS - 1) {
            res += ";";
        }
    }
    return res;
}

void AlarmManager::update(const DateTime& now) {
    for (uint8_t i = 0; i < MAX_ALARMS; i++) {
        if (!schedules[i].enabled) continue;
        
        bool isTriggered = false;

        if (schedules[i].isDaily) {
            // 毎日アラーム: 時・分だけをチェック
            if (now.hour() == schedules[i].hour &&
                now.minute() == schedules[i].minute) {
                
                if (lastTriggeredDay[i] != now.day()) {
                    isTriggered = true;
                    lastTriggeredDay[i] = now.day(); // ロック
                }
            }
        } else {
            // 1回限りアラーム: 年・月・日・時・分を全てチェック
            if (now.year() == schedules[i].year &&
                now.month() == schedules[i].month &&
                now.day() == schedules[i].day &&
                now.hour() == schedules[i].hour &&
                now.minute() == schedules[i].minute) {
                
                isTriggered = true;
            }
        }

        if (isTriggered) {
            Serial.printf("[Alarm] Slot %d triggered!\n", i);
            
            // スロットに対応した個別音声ファイルパス (WAV優先、MP3フォールバック)
            char path_wav[32];
            char path_mp3[32];
            snprintf(path_wav, sizeof(path_wav), "/alarm%d.wav", i);
            snprintf(path_mp3, sizeof(path_mp3), "/alarm%d.mp3", i);
            
            if (HAL_SD::fileExists(path_wav)) {
                AudioPlayer::playMP3(path_wav);
            } else if (HAL_SD::fileExists(path_mp3)) {
                AudioPlayer::playMP3(path_mp3);
            } else {
                Serial.printf("[Alarm Error] File not found: %s / %s\n", path_wav, path_mp3);
            }
            
            // 1回限りアラームの場合のみ、実行後に無効化してセーブ
            if (!schedules[i].isDaily) {
                schedules[i].enabled = false;
                saveSettings(i);
            }
        }
    }
}

bool AlarmManager::hasActiveAlarms() {
    for (uint8_t i = 0; i < MAX_ALARMS; i++) {
        if (schedules[i].enabled) return true;
    }
    return false;
}
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

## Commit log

2026-07-24 gitignoreを追加
2026-07-24 一式を追加
2026-07-24 スピーカー接続用コネクタをJST-PH2.0に変更
2026-07-24 EasyEDA設計データの更新（スピーカーコネクタ変更）
2026-07-31 ci: app のデバッグビルド用 GitHub Actions ワークフローを追加
2026-07-31 docs: app/README.md に GitHub Actions デバッグビルドの利用手順を追記
2026-07-31 ci: debug-* タグ Push 時に APK を GitHub Release Assets へアップロードする機能を追加
2026-07-31 docs: app/README.md に GitHub Release Assets からのダウンロード方法を追記
2026-08-17 回路: ESP32C3駆動時のノイズ対策として47uFバルクMLCCとパスコン強化・プルダウンを追加
2026-08-17 回路: EasyEDA回路図データへのノイズ対策部品(C9, C10, R12)反映と反映スクリプトの追加
2026-08-17 回路: タクトスイッチを横向きSMD部品(EVQPUC02K / C79174)に変更しEasyEDA回路図に反映
2026-08-17 回路: スピーカー接続用にJST SH 2ピンコネクタ(BM02B-SRSS-TB(LF)(SN) / C160388)を追加しEasyEDA回路図に反映
2026-08-17 回路: 電源接続用にJST PH 2ピンコネクタ(B2B-PH-K-S(LF)(SN) / C131337)を追加しEasyEDA回路図に反映
2026-08-17 回路: 5.1Vツェナーダイオードを在庫あり代替品(BZT52C5V1S / C2118)に変更しEasyEDA回路図に反映
2026-08-19 feat(firmware): Deep SleepモードおよびRTC/GPIO復帰機能の追加
2026-08-19 fix(firmware): BLEファイル転送の非同期化・スリープ抑止・高速化対応
2026-08-19 fix(app): BLEファイル転送の動的MTUパケット制御・リトライ・送信レート最適化
2026-08-19 fix(app): プリセット選択欄と音声転送ボタンのレイアウト崩れ・オーバーフローを修正
2026-08-19 feat(app): 音声プリセット管理機能およびホーム画面（SQLite永続化）を追加
2026-08-19 feat(app): 音声試聴（プレビュー再生）機能を追加（プリセット編集・デバイス転送画面）
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2026-08-19 style(app): ホーム画面のサブタイトル表記を「ボイス & アラーム コントローラー」に変更
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2026-08-19 ci: setup-python の requirements.txt キャッシュ指定を削除
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2026-08-19 fix(app): ファームウェア更新画面のBLE接続UIをデバイス設定画面のボトムシート方式に統一
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2026-08-19 fix: デバイス設定・転送画面から戻る際の二重Popによる画面消失バグを修正
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2026-08-25 feat(shell): 外装ケース一式（3Dモデル・アクリル加工データ・ビルドスクリプト）を追加
    [acrylic_panel.dxf, acrylic_panel.scad, acrylic_panel.stl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]
2026-08-25 feat(shell): 前面ボタンのナット接着ポケットおよび磁石を2個（左右中央）配置へ変更
    [acrylic_panel.dxf, acrylic_panel.scad, acrylic_panel.stl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]
2026-08-25 feat(shell): WS2812B用導光スリット窓およびアセンブリLEDモックアップを追加
    [bottom_case.stl, front_button.scad, front_button.stl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]
2026-08-27 fix(shell): 電池ボックス新寸法(63x37x17mm)対応とボトムケース内部構造・高さの調整
    [bottom_case.scad, bottom_case.stl, front_button.stl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]
2026-08-27 fix(shell): ネジボスの破損防止に向けた根元テーパーと補強ガセットリブの追加
    [bottom_case.scad, bottom_case.stl, front_button.stl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]
2026-08-27 feat(shell): M2六角ネジスペーサー(20mm+6mm)対応に伴うボトム受け座化と締結構造の刷新
    [bottom_case.scad, bottom_case.stl, front_button.stl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]
2026-08-27 fix(shell): 音量調整用スリット開口位置を前方向へ5mmオフセット
    [bottom_case.stl, front_button.stl, params.scad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]
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2026-08-27 feat(shell): 前面ボタンのバネ構造追加・開口枠整合・タクトスイッチ干渉解消
    [bottom_case.scad, bottom_case.stl, front_button.scad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]
2026-08-27 feat(shell): 実基板タクトスイッチ内側配置に合わせた前面ボタンのプランジャー最適化とソリッド一体化
    [bottom_case.stl, front_button.scad, front_button.stl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]
2026-08-27 feat(shell): トップ・ボトム・ボタンの一括スタック3Dプリントプレート(print_plate_all)を追加
    [print_plate.scad, print_plate_all.stl]
2026-08-27 fix(shell): アセンブリモックアップにおけるアクリル化粧パネルの配置基準面補正と接触検証画像の追加
    [main_assembly.scad]
2026-08-28 前面ボタンの高さを20mmに変更しモデル・出力ファイルを更新
    [acrylic_panel.dxf, acrylic_panel.stl, bottom_case.stl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]
2026-08-28 feat(shell): 一括印刷プレート(print_plate_all)の切り離しリブを外周リム四隅に再配置
    [bottom_case.stl, front_button.stl, print_plate.scad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]
2026-08-28 feat(shell): 前面ボタンをネオジム磁石内蔵・化粧パネルをM2六角ナット仕様に変更
    [acrylic_panel.dxf, acrylic_panel.scad, acrylic_panel.stl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]
2026-08-28 前面ボタンをM2ネジ式アジャスタブル・プランジャー構造に設計変更
    [bottom_case.stl, front_button.scad, front_button.stl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]
2026-08-28 前面ボタンのスイッチ押下プランジャー機構を廃止
    [bottom_case.stl, front_button.scad, front_button.stl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]
2026-08-28 Revert "前面ボタンのスイッチ押下プランジャー機構を廃止"
    This reverts commit f6d1a9818fbeadc0217cc8bee56e0ebc9ac59124.
    [bottom_case.stl, front_button.scad, front_button.stl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]
2026-08-28 前面ボタンM2ネジ式アジャスタブル・プランジャー復帰に伴うSTLファイルを更新
    [bottom_case.stl, front_button.stl, print_plate_all.stl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]
2026-08-28 前面ボタンの復帰バネを樹脂製板バネから市販マイクロコイルスプリング方式に変更
    [bottom_case.scad, bottom_case.stl, front_button.scad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]
2026-08-28 fix(shell): 前面ボタンのフランジ高さを調整しトップカバーとの干渉を解消
    [bottom_case.stl, front_button.scad, front_button.stl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]
2026-08-28 fix(shell): スピーカーの出音口向き（前後反転）と固定ボス位置・クリアランスの適正化
    [bottom_case.scad, bottom_case.stl, front_button.stl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]
2026-08-28 fix(shell): 電池ボックスガイドリブの肉厚強化・三角補強リブ追加および側壁一体化
    [bottom_case.scad, bottom_case.stl, front_button.stl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]
2026-08-28 fix(shell): メイン基板20mmスペーサー対応に伴う右側面ボリュームスリットのUノッチ化およびZ位置補正
    [bottom_case.scad, bottom_case.stl, front_button.stl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]
2026-08-28 fix(shell): メイン基板20mmスペーサー対応に伴う前面ボタンM2プランジャー位置補正および基板干渉回避Dカットの追加
    [bottom_case.stl, front_button.scad, front_button.stl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]
2026-08-28 fix(shell): 前面ボタンのインセットポケット化およびケース手前側壁の前方3mm拡張
    [bottom_case.scad, bottom_case.stl, front_button.scad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]
2026-08-28 chore(shell): 不要な旧検証画像の削除および自動生成プレビュー画像・STLファイルの再生成
    [bottom_case.stl, front_button.stl, print_plate_all.stl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]
2026-08-28 feat(shell): トップカバーのねじ穴貫通・ザグリ穴加工および上下両締めM2締結構造への更新
    [bottom_case.stl, cutaway_assembly.scad, front_button.stl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]
2026-08-28 feat(shell): ボトムケース手前前面壁にスピーカー出音用スリットを追加
    [bottom_case.scad, bottom_case.stl, front_button.stl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]
2026-08-28 feat(shell): 電池ボックス底面取り出し構造および回転ロック・スイッチ操作窓を追加
    [battery_lid.scad, battery_lid.stl, bottom_case.scad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]
2026-08-28 build(shell): main_assembly_closed.stl の自動生成処理追加と最新モデルへの更新
    [main_assembly_closed.stl]
2026-08-28 fix(shell): 回転ロックダイヤルを底面から0.2mm奥へ完全沈め込み、卓上接地時のガタつきを解消
    [battery_lid.scad, battery_lid.stl, bottom_case.scad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]
2026-08-29 fix(shell): 電池ボックス開口ベイ奥側の浮遊壁を撤去し、背面壁・底面一体型の高剛性ガイドリブおよび回転ロックボス補強台座に再設計
    [battery_lid.stl, bottom_case.scad, bottom_case.stl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]
2026-08-29 fix(shell): スピーカー固定位置を前面方向へ2.5mm移動し電池ボックスとの干渉を解消（クリアランス1.75mm確保）
    [battery_lid.stl, bottom_case.scad, bottom_case.stl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]
2026-08-29 fix(shell): 電池ボックス天井ストッパーをボリュームスリット非干渉型の高剛性構造（下面45度ブレース＆幅20mm全面支持）に強化
    [battery_lid.stl, bottom_case.scad, bottom_case.stl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]
2026-08-29 電池フタのスイッチアクセス開口窓を拡大し操作性を改善
    [battery_lid.scad, battery_lid.stl, bottom_case.stl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]
2026-08-29 ボトムケースと電池フタの干渉解消のためフタ外形を縮小し各部クリアランスを拡大
    [battery_lid.scad, battery_lid.stl, bottom_case.scad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]
2026-08-29 ボトムケース側の電池フタ受け座を内側へ盛り上げ肉厚を2.0mmに強化し折損を防止
    [battery_lid.stl, bottom_case.scad, bottom_case.stl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]
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2026-08-29 ボトムケース四隅M2ネジ穴の締結座面肉厚を2.0mmに増強し締め付け割れを防止
    [battery_lid.stl, bottom_case.stl, front_button.stl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]
2026-08-29 底面外装および電池フタの爪部分をボトム内側アンダーカット潜り込み引っ掛け構造に変更し浮き上がりを完全防止
    [battery_lid.scad, battery_lid.stl, bottom_case.scad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]
2026-08-29 回転ロックダイヤルを中心ネジ貫通式に変更し底面外側からボトム側ボスへM2ネジ締結する構造を実装
    [battery_lid.stl, bottom_case.scad, bottom_case.stl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]
2026-08-29 一括3Dプリントプレート（print_plate_all.stl）から前面ボタンを除外
    [print_plate.scad, print_plate_all.stl]
2026-08-29 一括3Dプリントプレートを内部内包スタック構造に刷新しニッパー切り離しサポートを追加
    [print_plate.scad, print_plate_all.stl]
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2026-08-29 一括3Dプリントプレートからトップと電池フタ間の宙浮き・めり込みサポートピラーを削除
    [print_plate.scad, print_plate_all.stl]
2026-08-29 一括3Dプリントプレートの回転ロックダイヤル支持ピラーを着地させ水平ランナーで連結して宙浮きを解消
    [print_plate.scad, print_plate_all.stl]
2026-08-29 一括3Dプリントプレートの回転ロックダイヤル支持ピラーを下面内側へ確実に命中させ左右並列ランナーで凹みを避けて宙浮きを完全解消
    [print_plate.scad, print_plate_all.stl]
2026-08-29 回転ロックダイヤル支持ピラーをボトムケース奥壁天端（Y=34.5mm）に完全着地させ宙浮きを解消
    [print_plate.scad, print_plate_all.stl]
2026-08-30 fix(shell): ボトムケース前面ボタン受け座ボスの耐折損性・高剛性化改善
    [battery_lid.stl, bottom_case.scad, bottom_case.stl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]
2026-08-30 fix(shell): 前面ボタンのタクトスイッチ押下用ネジ位置を2mm上方向へシフト（基板接触を回避）
    [battery_lid.stl, bottom_case.stl, front_button.stl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]
2026-08-30 feat(shell): 基板上5mmスペーサー締結に対応（トップカバーボス高短縮4mm・M2x8mmネジ締結）
    [battery_lid.stl, bottom_case.stl, front_button.stl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]
2026-08-30 fix(shell): 電池フタのスイッチアクセス開口窓を実機スイッチに合わせて後方へ5mmシフト
    [battery_lid.stl, bottom_case.stl, front_button.stl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]
2026-08-30 fix(shell): 前面ボタンのネオジム磁石圧入不良解消のためポケット径をφ6.4mmへ拡張し導入テーパーを追加
    [front_button.scad, front_button.stl, params.scad]
2026-08-30 feat(shell): ボリューム調整スリットの操作性改善（上下ケースすり鉢状指掛かりスカラップ追加・開口拡大）
    [battery_lid.stl, bottom_case.scad, bottom_case.stl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]
2026-08-31 feat(shell): ボリュームスリット内側補強土手（裏打ちフレーム）追加による肉厚補強（純残存肉厚2.0mm確保）
    [battery_lid.stl, bottom_case.scad, bottom_case.stl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]
2026-08-31 fix(shell): トップカバーと前面ボタン間の隙間および干渉の解消
    - 前面壁を貫通していたアクリル用リセス(深さ3mm)を撤廃し前面壁を復元
    - ボタン開口部高さを20mmから18mmに最適化しトップカバー側に2.8mmの壁肉厚を確保
    - ボタンフランジ高さを19.2mmに調整しトップカバー天井との干渉(+0.7mm)を解消(クリアランス0.2mm確保)
    - ボタン全周のクリアランスを0.4mmに統一し上下の抜け止め座面を確実に形成
    - 各3Dプリント用STLファイルおよびプレビュー画像・仕様書(README)を更新
    [acrylic_panel.dxf, acrylic_panel.scad, acrylic_panel.stl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]
2026-08-31 fix(shell): 前面ボタン全厚を6.0mmに増厚しM2ネジ貫通を完全防止
    - ボタンキャップ厚みを2.5mmから4.2mmへ、フランジ厚みを1.2mmから1.8mmへ増厚（ボタン全厚3.7mm→6.0mm）
    - M2タップ下穴深さを2.0mmから2.5mmへ最適化し、穴底から表面まで2.0mmの安全肉厚を確保
    - M2x4mmネジを締め切っても表面を突き破らない0.5mm以上のマージンを確保
    - ケース外壁からのボタン突出量を2.2mmに拡大し、押し心地とガイド剛性を向上
    - 各種STLファイルおよびプレビュー画像・仕様書(README)を更新
    [battery_lid.stl, bottom_case.stl, front_button.scad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]
2026-08-31 fix(shell): 薄肉警告部（A:0.6mm, B:0.33mm, C:0.25mm）を0.8mm以上に肉厚強化しSTL/プレビューを更新
    [battery_lid.scad, battery_lid.stl, bottom_case.scad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]
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2026-09-14 fix(app): ファームウェア更新画面の利用可能なファームウェアラベル横のリポジトリ名表示を削除
2026-09-14 fix(firmware): 音声再生ループ内の事前8000バイト強制ミュートを削除し末尾消音バグを解消
2026-09-14 fix(app): 音声トランスコード処理をネイティブ直接変換・フォールバック対応に刷新
